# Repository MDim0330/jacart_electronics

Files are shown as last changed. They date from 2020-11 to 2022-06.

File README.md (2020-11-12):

**JACart Electronics Repo**

Contain Python and Arduino controller code for managing the Teleop board.

**Repo Contents**

cart_teleop_dac:/ Updated Arduino teleop code that utilizes DACs instead of PWM signals. This version should be the one used going forward.

python_teleop:/ Stand-alone python controller for teleop_board

libs:/ Require libraries for operating the Arudino teleop code

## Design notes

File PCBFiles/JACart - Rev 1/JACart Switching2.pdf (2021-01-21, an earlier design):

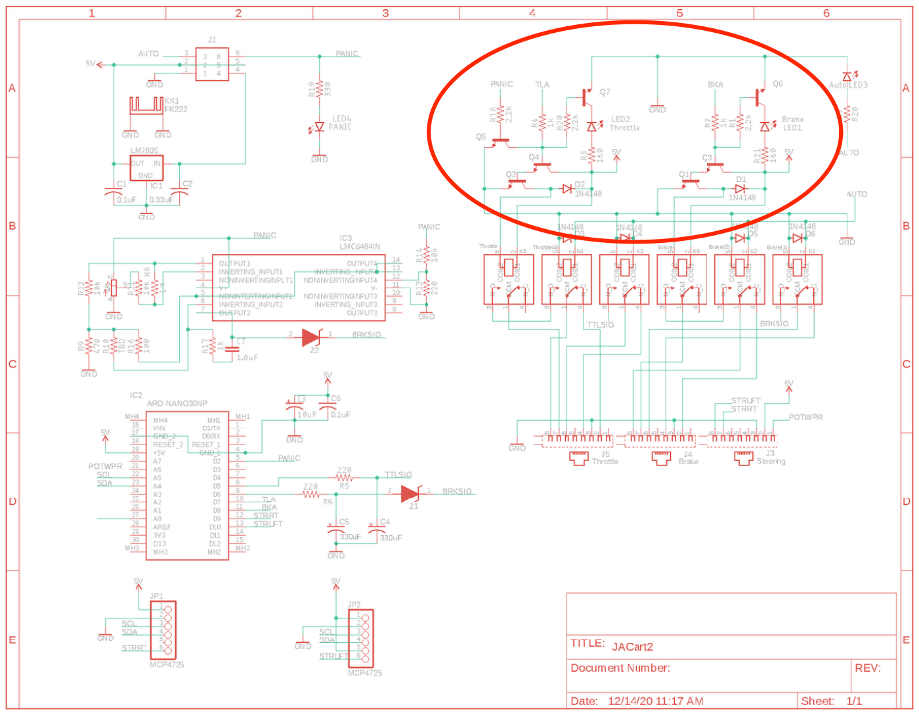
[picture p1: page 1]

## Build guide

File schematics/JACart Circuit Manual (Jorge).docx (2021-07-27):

JACart Circuit Manual:

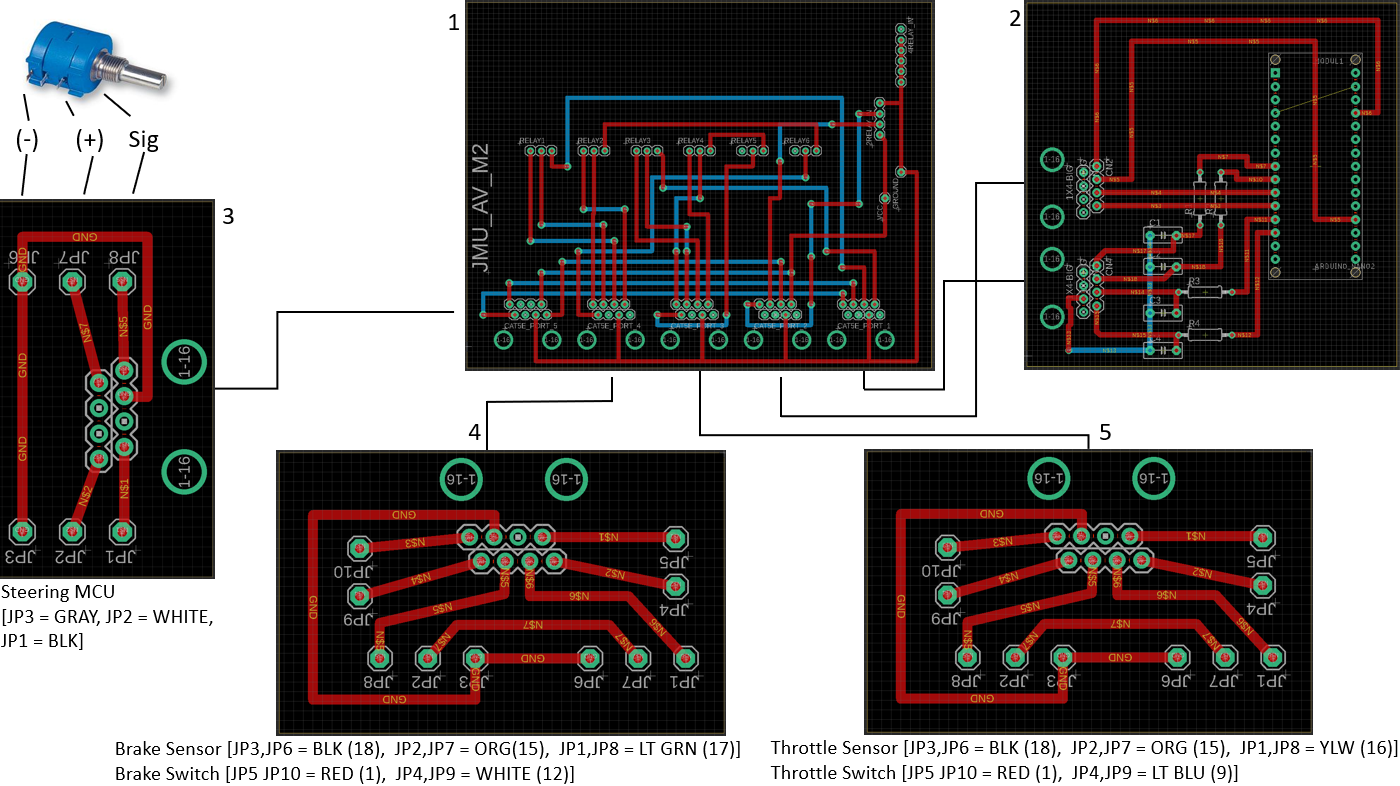
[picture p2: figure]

This manual will review steering, brake, throttle circuits used in the golf cart as of April 2020. Below is an overview of the electronic components involved. A description of each individual board is detailed in subsequent paragraphs.

Figure 1: Complete view of steering, brake, and throttle components in the golf cart.

Overview:

The (INSERT GOLF CART NAME HERE) is selected by the team for this project extension from and earlier model because (WHY DID WE SELECT THIS MODEL?). For the primary controls, i.e., steering, braking and throttle, five individual boards are used: 1 - Motherboard, 2 - Arduino Board, 3 – Steering Board, 4 - Brake Board, 5 - Throttle Board. Each board has its own individual task when in Autonomous Mode.

Each board in Figure 1 was produced by using Eagle Cad. The board view is the only thing visible in this diagram as it is an overview. The solid lines interconnecting each board to the Motherboard represent CAT5e Ethernet cables.

The components needed to exactly replicate this design requires the following:

- Potentiometer (1 required)
  - https://www.digikey.com/product-detail/en/bourns-inc/3590S-2-103L/3590S-2-103L-ND/1088586
- 2-Channel Relay (1 required)
  - https://www.sainsmart.com/products/2-channel-5v-relay-module
- 4-Channel Relay (1 required)
  - https://www.sainsmart.com/products/4-channel-5v-relay-module
- CAT5e Module (10 required)
  - https://www.digikey.com/product-detail/en/assmann-wsw-components/A-2004-2-4-LP-S-R/AE10388-ND/2183639
- Wire to Block Terminal (4 – Two Piece, 6 – Three Piece)
  - https://www.digikey.com/product-detail/en/on-shore-technology-inc/OSTTC022162/ED2609-ND/614558
- Arduino Nano (1 required)
  - https://www.arduino.cc/en/pmwiki.php?n=Main/ArduinoBoardNano
- (###) Resistor (4 required)
  - Link
- (###) Capacitor (4 required)
  - Link

The placement of all these components are discussed in their respective sections in this manual. Text boxes below the steering board, brake board, and throttle board have the specific wires that provide input needed for proper operation. The names of corresponding modules are labeled first, followed by their designated 36-pin MCU connector wire color and pin number connection.

Figure 2 illustrates the main wiring diagram for the golf cart. There are arrows identifying the four specific connection points used for the brake and throttle boards.

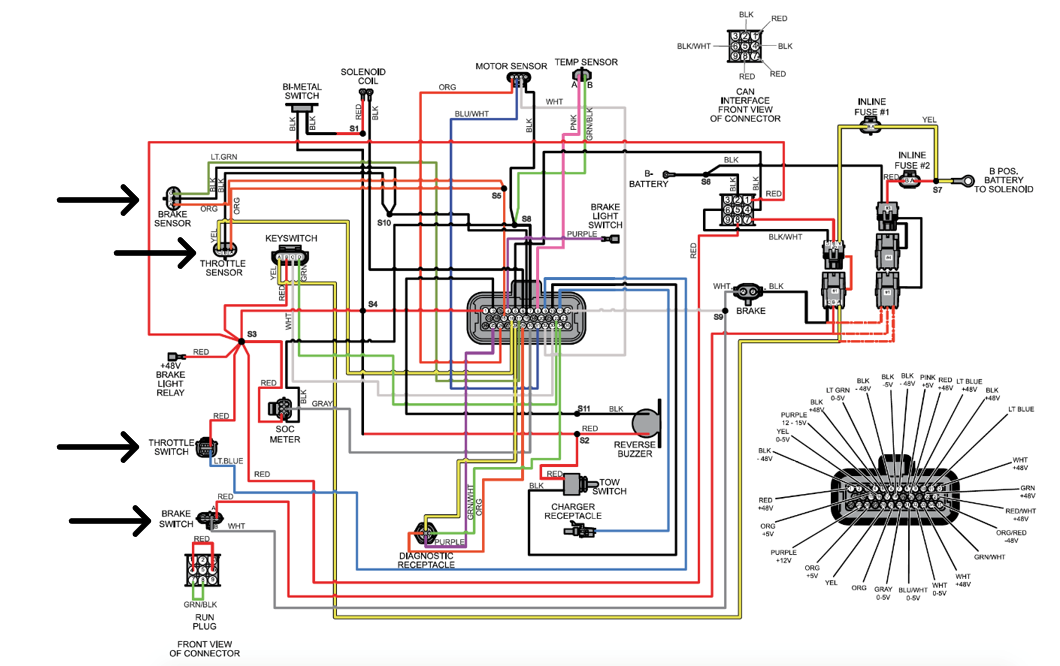
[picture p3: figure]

Figure 2: Main Wiring Harness Diagram of the 36-pin connector from the Golf Cart MCU

1 – Motherboard:

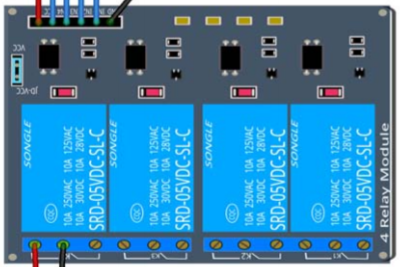
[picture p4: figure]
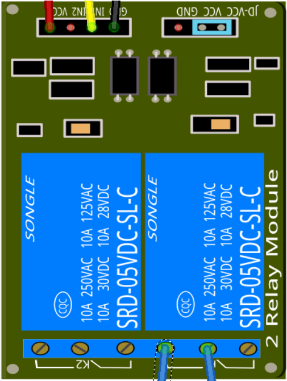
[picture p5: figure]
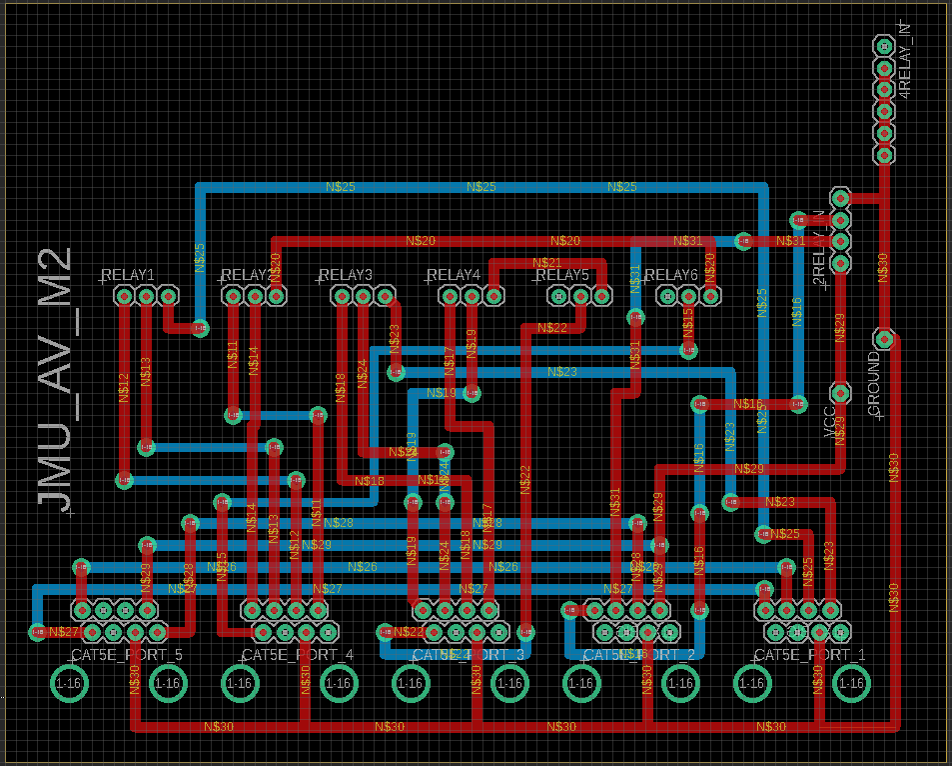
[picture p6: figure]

}

Figure 3: Enlarged Board View (Eagle Cad) of Motherboard and components.

The Motherboard is the main hub for the golf cart’s electronic components. The materials needed to assemble this component completely are: 2-Channel Relay, 4-Channel Relay, 5 Cat5e Modules. The relays will be wired as shown in Figure 3. The 5 Cat5e modules will be placed in the bottom portion of the board. The silkscreen layer of the board has multiple labels named, “CAT5E_PORT#”. These numbers correspond to the boards that we designed as a prototype. Do not pay too much attention to these numbers since the boards each of these ports are assigned to are labeled properly in Figure 1. The upper portion of the board is divided into six segments of 3 wires for each individual relay to make the soldering between board and relays much smoother. The wiring diagram of this board can be seen below in order to better understand.

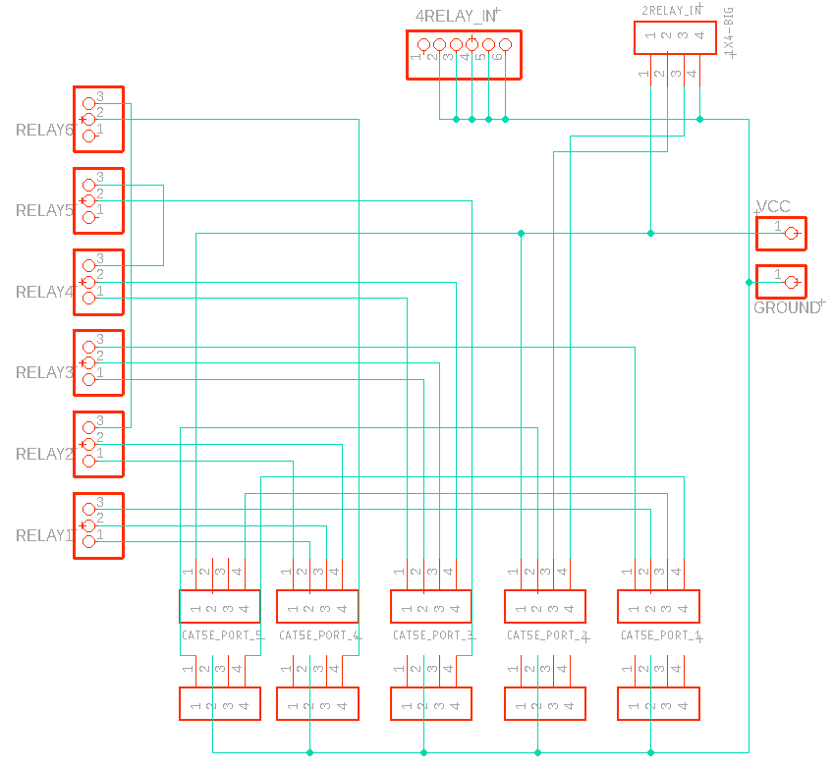
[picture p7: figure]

Figure 4: Enlarged Schematic View of Motherboard component wiring.

2 – Arduino Board:

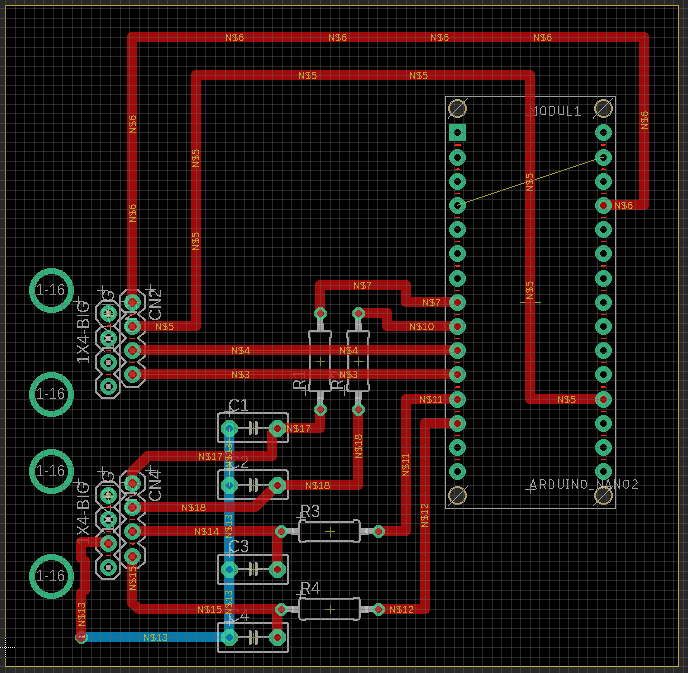
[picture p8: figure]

Figure 5: Enlarged Board View (Eagle Cad) of Arduino Board and components.

(Insert Text Here)

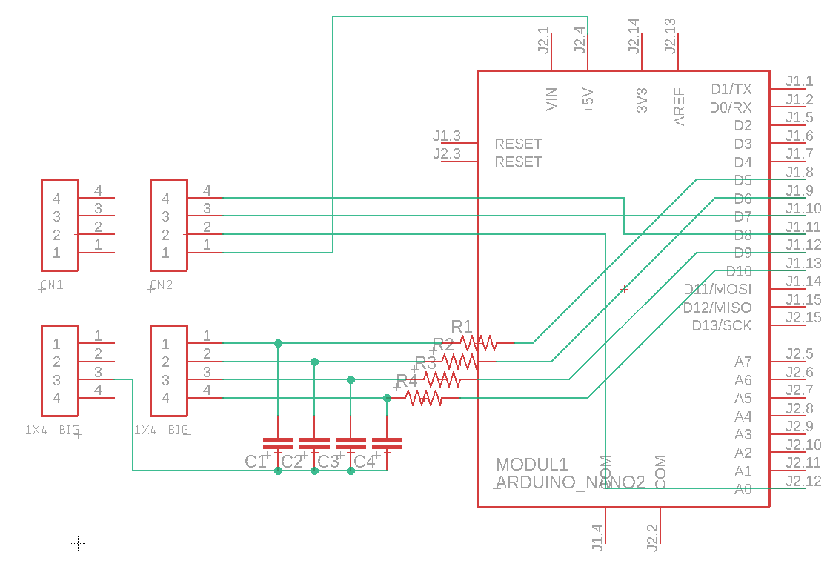
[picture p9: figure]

Figure 6: Enlarged Schematic View of Arduino Board component wiring.

3 – Steering Board:

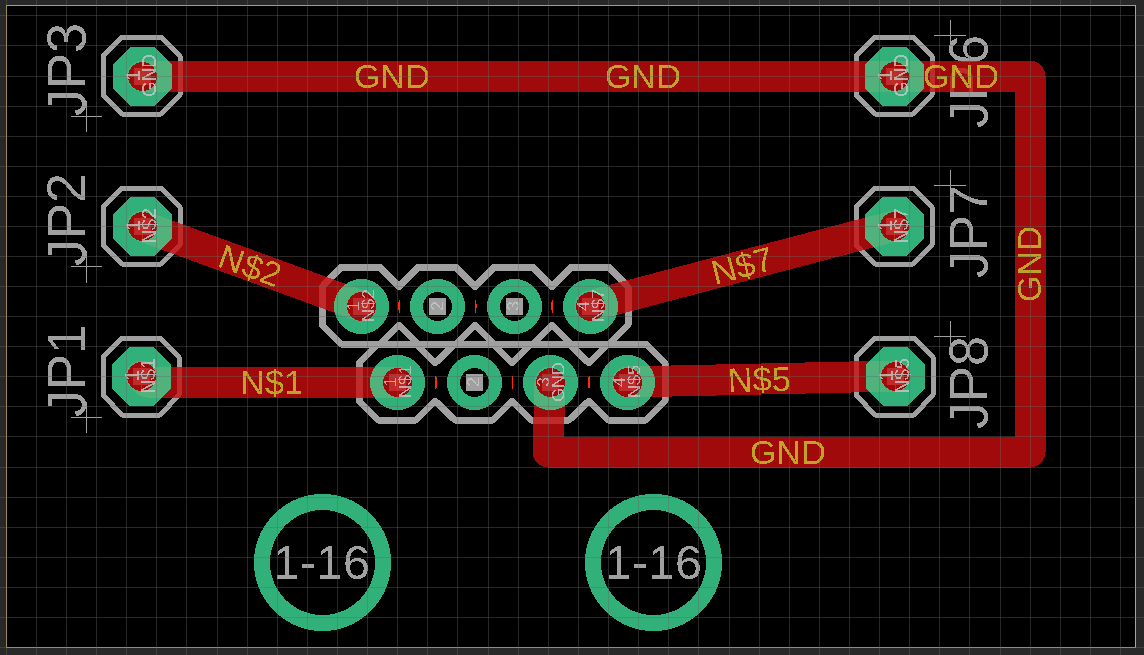
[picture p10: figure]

Figure 7: Enlarged Board View (Eagle Cad) of Steering Board and components.

The Steering board allows us to control all the directional movements within the golf cart. This board only requires a single Cat5e Module that will be placed at the center of the board where the 8 pins are found together. The pins JP6 – JP8 are connected directly to the potentiometer (see Figure 1). This connection allows recovering the current steering wheel rotational position to ensure we are turning at the commanded angle when in Autonomous Mode. This potentiometer is attached to the shaft of the steering column utilizing a custom mount that we had 3D printed. The potentiometer was able to turn and read the angle with a set of gears that were attached to steering column. Pins JP1-JP3 provide access to the Steering MCU so that we may mechanically move the steering to our desired angle when moving autonomously. Figure 8 shows the schematic view of this board.

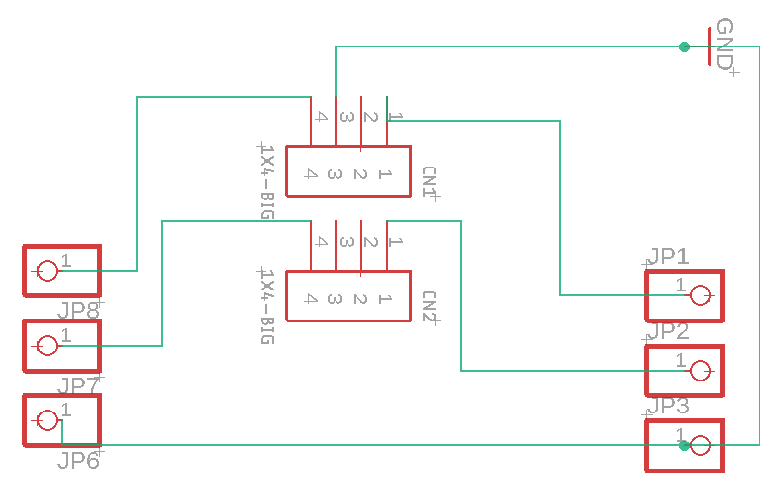
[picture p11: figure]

Figure 8: Enlarged Schematic View of Steering Board component wiring.

4/5 – Brake/Throttle Board:

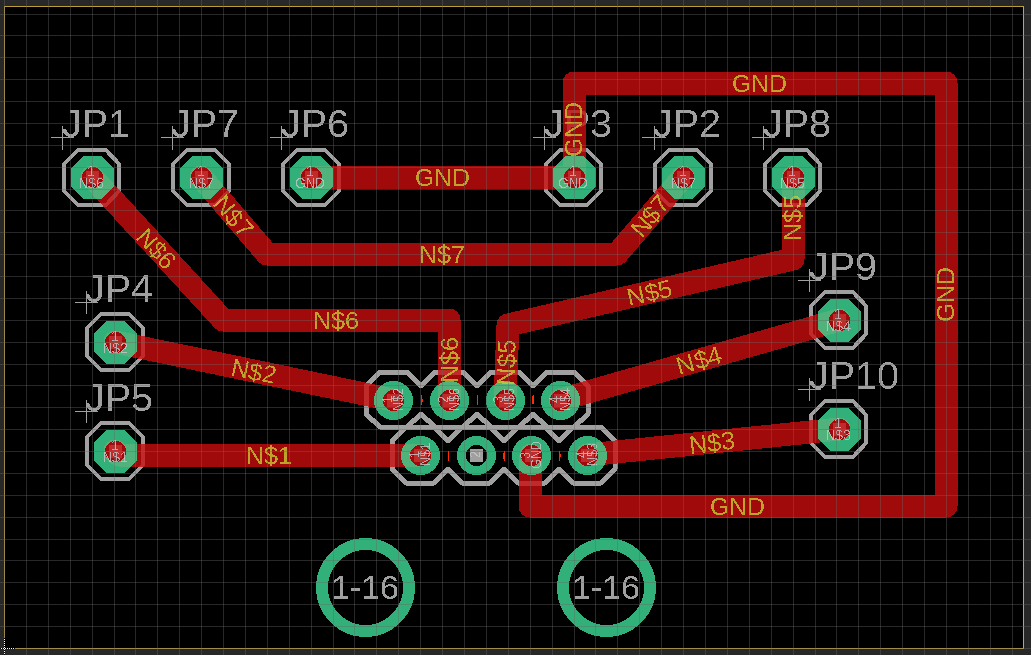
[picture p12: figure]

Figure 9: Enlarged Board View (Eagle Cad) of Brake/Throttle Board and components.

The Brake/Throttle Board requires a single Cat5e Module placed at the center similar to the steering board. These four different sets of pins correspond to individual components found on the golf cart.

The pins on JP1, JP7, JP6, JP3, JP2, JP8 will all be a splice from the Brake Sensor and the Throttle Sensor (each on their respective boards). The pins that are directed toward the MCU here are very important as the voltage inputted into the MCU is the important thing here as this will tell the golf cart how much to accelerate.

The pins on JP4, JP5, JP9, JP10 will all be a splice from the Brake Sensor and the Throttle Sensor (on their respective boards). The switch is used to see when the Brake/Throttle pedals are actually pressed and is sent back to the Motherboard (NEED TO FIGURE THIS OUT MORE AND WRITE MORE ABOUT IT)

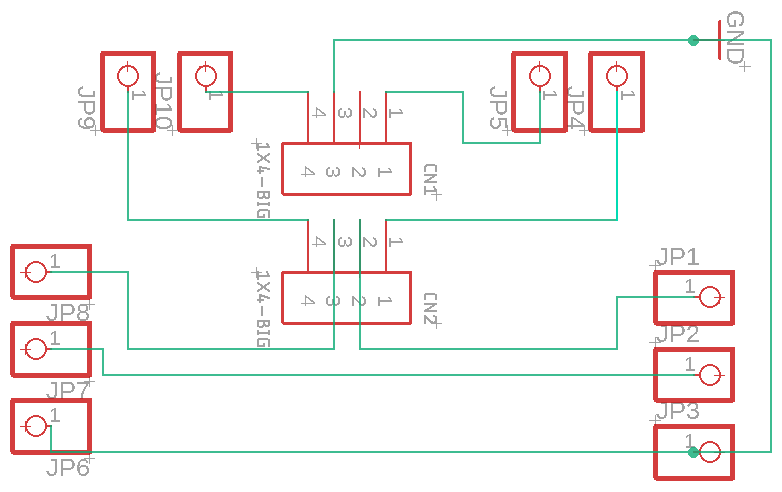
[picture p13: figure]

Figure 10: Enlarged Schematic View of Brake/Throttle Board component wiring.

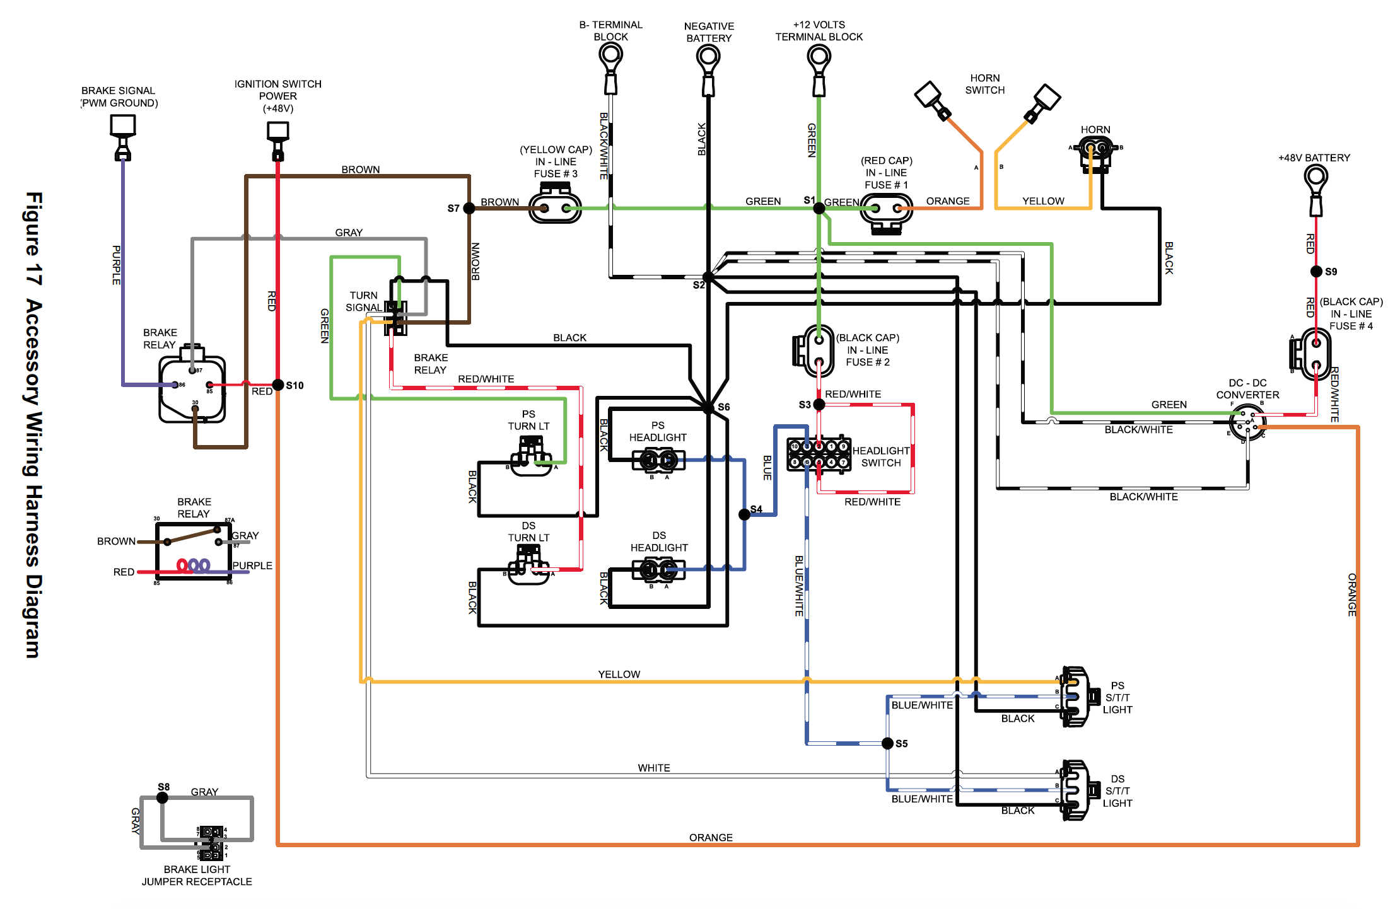
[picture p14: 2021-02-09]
schematics/Golf Cart Wiring #2.png

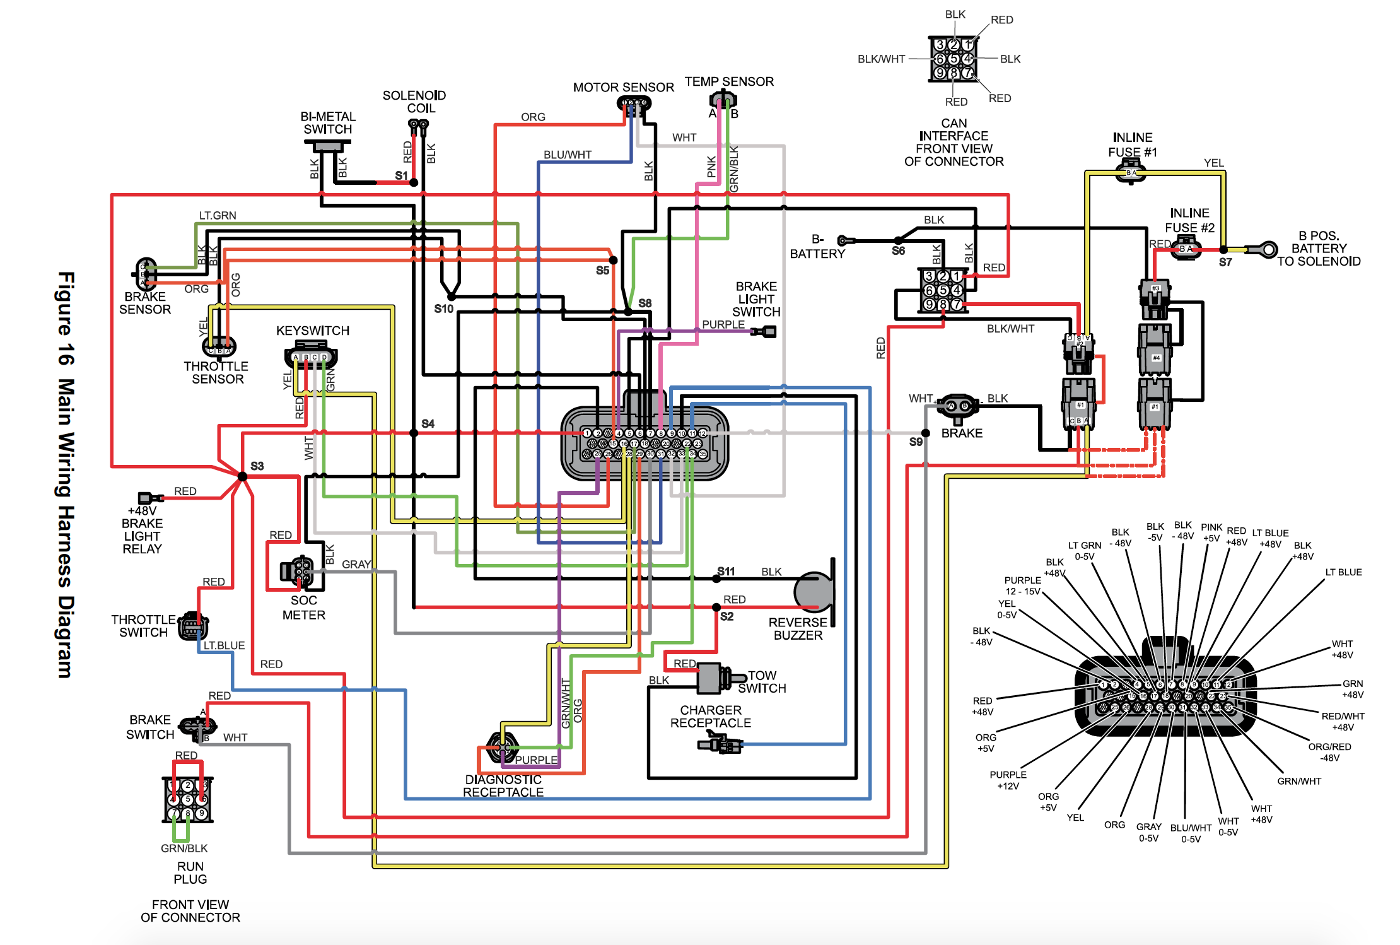
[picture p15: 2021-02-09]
schematics/Golf Cart Wiring #1.png

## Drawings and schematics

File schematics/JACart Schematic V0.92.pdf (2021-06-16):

## Steering Board (#3)

Pot | PSU | MCU

## Brake Board (#4)

Sensor | Switch | MCU

## Throttle Board (#5)

Sensor | Switch | MCU

## Relay Board (#1)

Port 2 | Port 1
Port 3 | Port 4 | Port 5

## Arduino Board (#2)

CN2 | CN4

## USB From Navigation Application

# System Block Diagram Sheet 1

# Board #1: Relay Board Sheet 2 (2021/6/15)

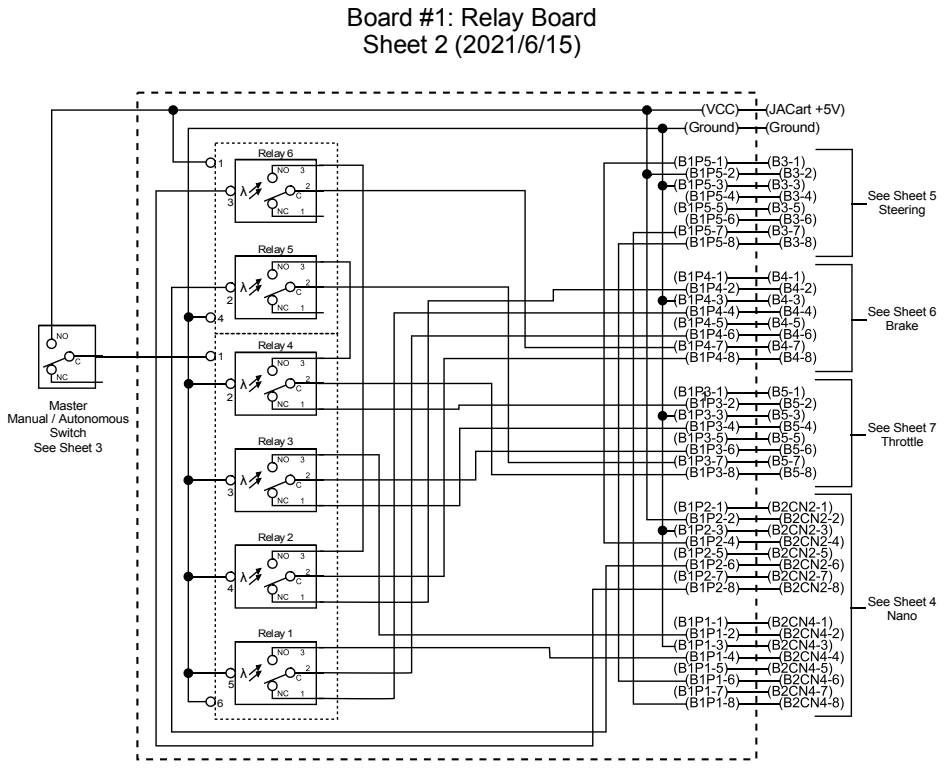
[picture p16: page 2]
Relay 1; Relay 6; Relay 5; Relay 4; Relay 3; Relay 2; (JACart +5V) (Ground); Master Manual / Autonomous Switch See Sheet 3; See Sheet 4 Nano; See Sheet 7 Throttle; See Sheet 6 Brake; See Sheet 5 Steering; (VCC) (Ground)

# Manual / Autonomous Switching Sheet 3

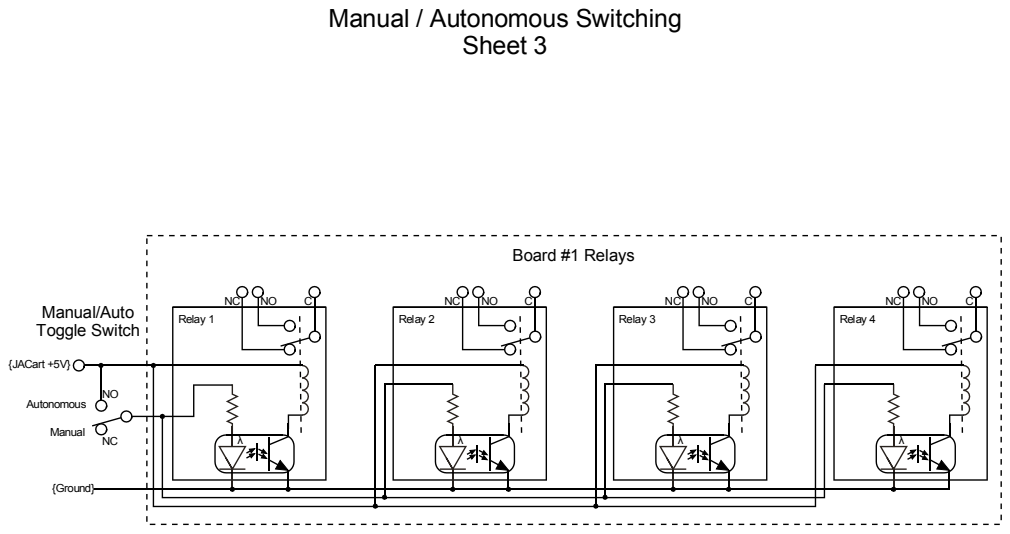
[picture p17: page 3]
Relay 1; Relay 2; Relay 3; Relay 4; {Ground}; {JACart +5V}; Manual; Autonomous; Board #1 Relays; Manual/Auto Toggle Switch

## Navigation Application

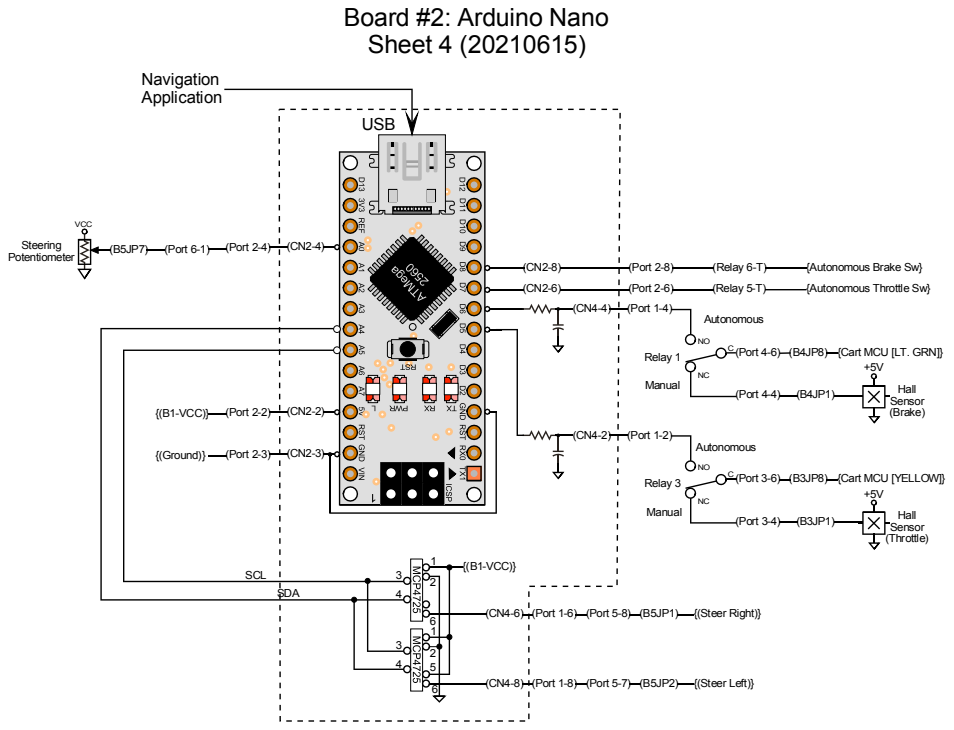
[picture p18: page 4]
Hall Sensor (Throttle); (Port 3-4); (Port 1-2); Relay 3; (Port 3-6) (B3JP8); Manual; Autonomous; {Cart MCU [YELLOW]}; (Port 2-6); (Relay 5-T); {Autonomous Throttle Sw}; Hall Sensor (Brake); (Port 4-4); (Port 1-4); Relay 1; (Port 4-6) (B4JP8); {Cart MCU [LT. GRN]}; (Port 6-1); (Port 2-4); VCC; Steering; Potentiometer; (Port 2-8); (Relay 6-T); {Autonomous Brake Sw}; USB; {(B1-VCC)}; (Port 2-2); {(Ground)}; (Port 2-3); SDA; SCL; (CN4-6) (Port 1-6) (Port 5-8) (B5JP1); {(Steer Right)}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

Board #2: Arduino Nano
Sheet 4 (20210615)

# Board #3: Steering Sheet 5

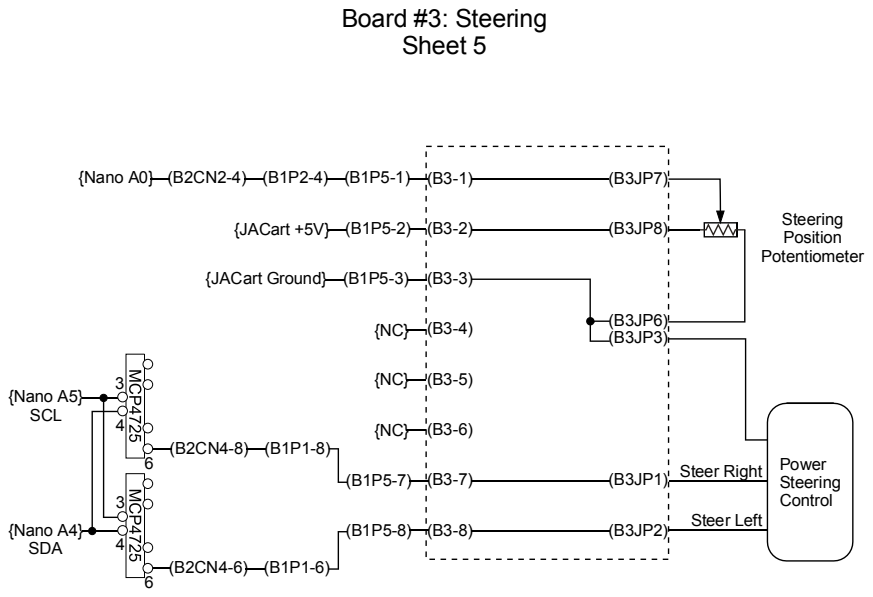
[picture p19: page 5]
Steer Left; Steering Control; Steering Position Potentiometer; {JACart +5V} (B1P5-2); {Nano A0} (B2CN2-4) (B1P2-4) (B1P5-1); {JACart Ground} (B1P5-3); {Nano A5}; {Nano A4}; SCL; SDA

Steer Right Power

# Board #4: Brake Sheet 6

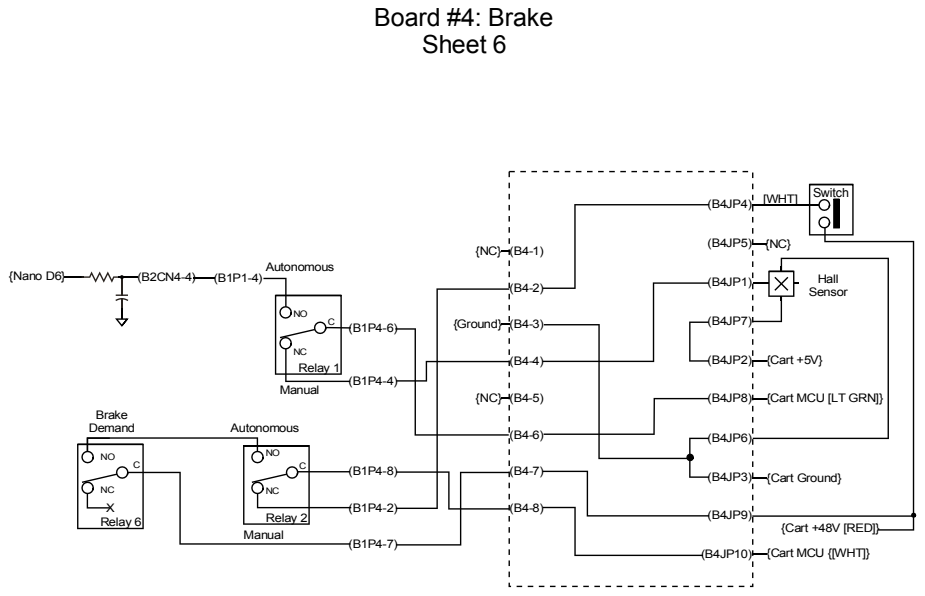
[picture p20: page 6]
{Cart +5V}; {Cart Ground}; Hall Sensor; [WHT]; Switch; Relay 1; Manual; Autonomous; {Nano D6}; {Ground}; Relay 6; Relay 2; Brake Demand

{Cart MCU [LT GRN]}

{Cart +48V [RED]}
{Cart MCU {[WHT]}

# Board #5: Throttle Sheet 7

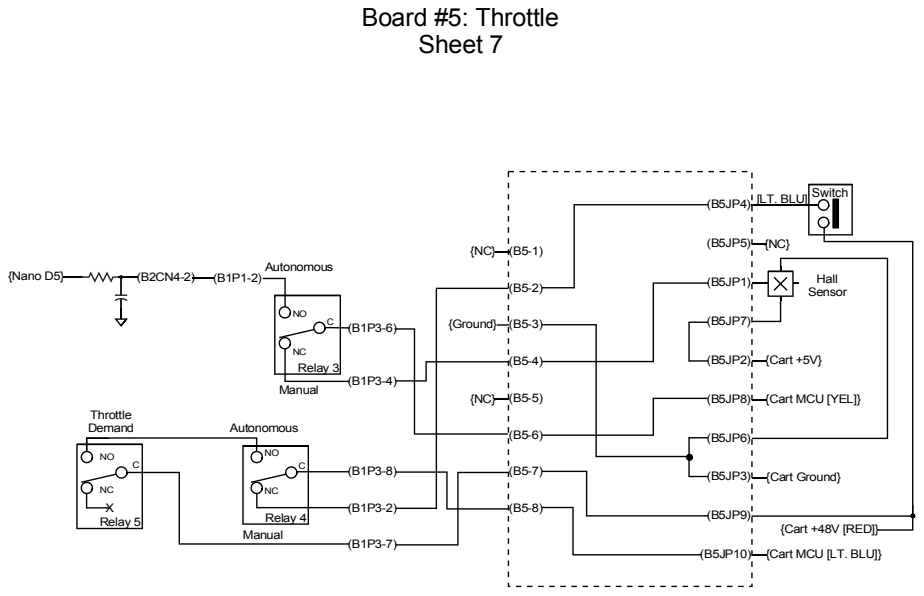
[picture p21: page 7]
{Cart +5V}; {Cart Ground}; Hall Sensor; [LT. BLU]; Switch; Relay 3; Manual; Autonomous; {Nano D5}; {Ground}; Relay 5; Relay 4; Throttle Demand

{Cart MCU [YEL]}

{Cart +48V [RED]}
{Cart MCU [LT. BLU]}

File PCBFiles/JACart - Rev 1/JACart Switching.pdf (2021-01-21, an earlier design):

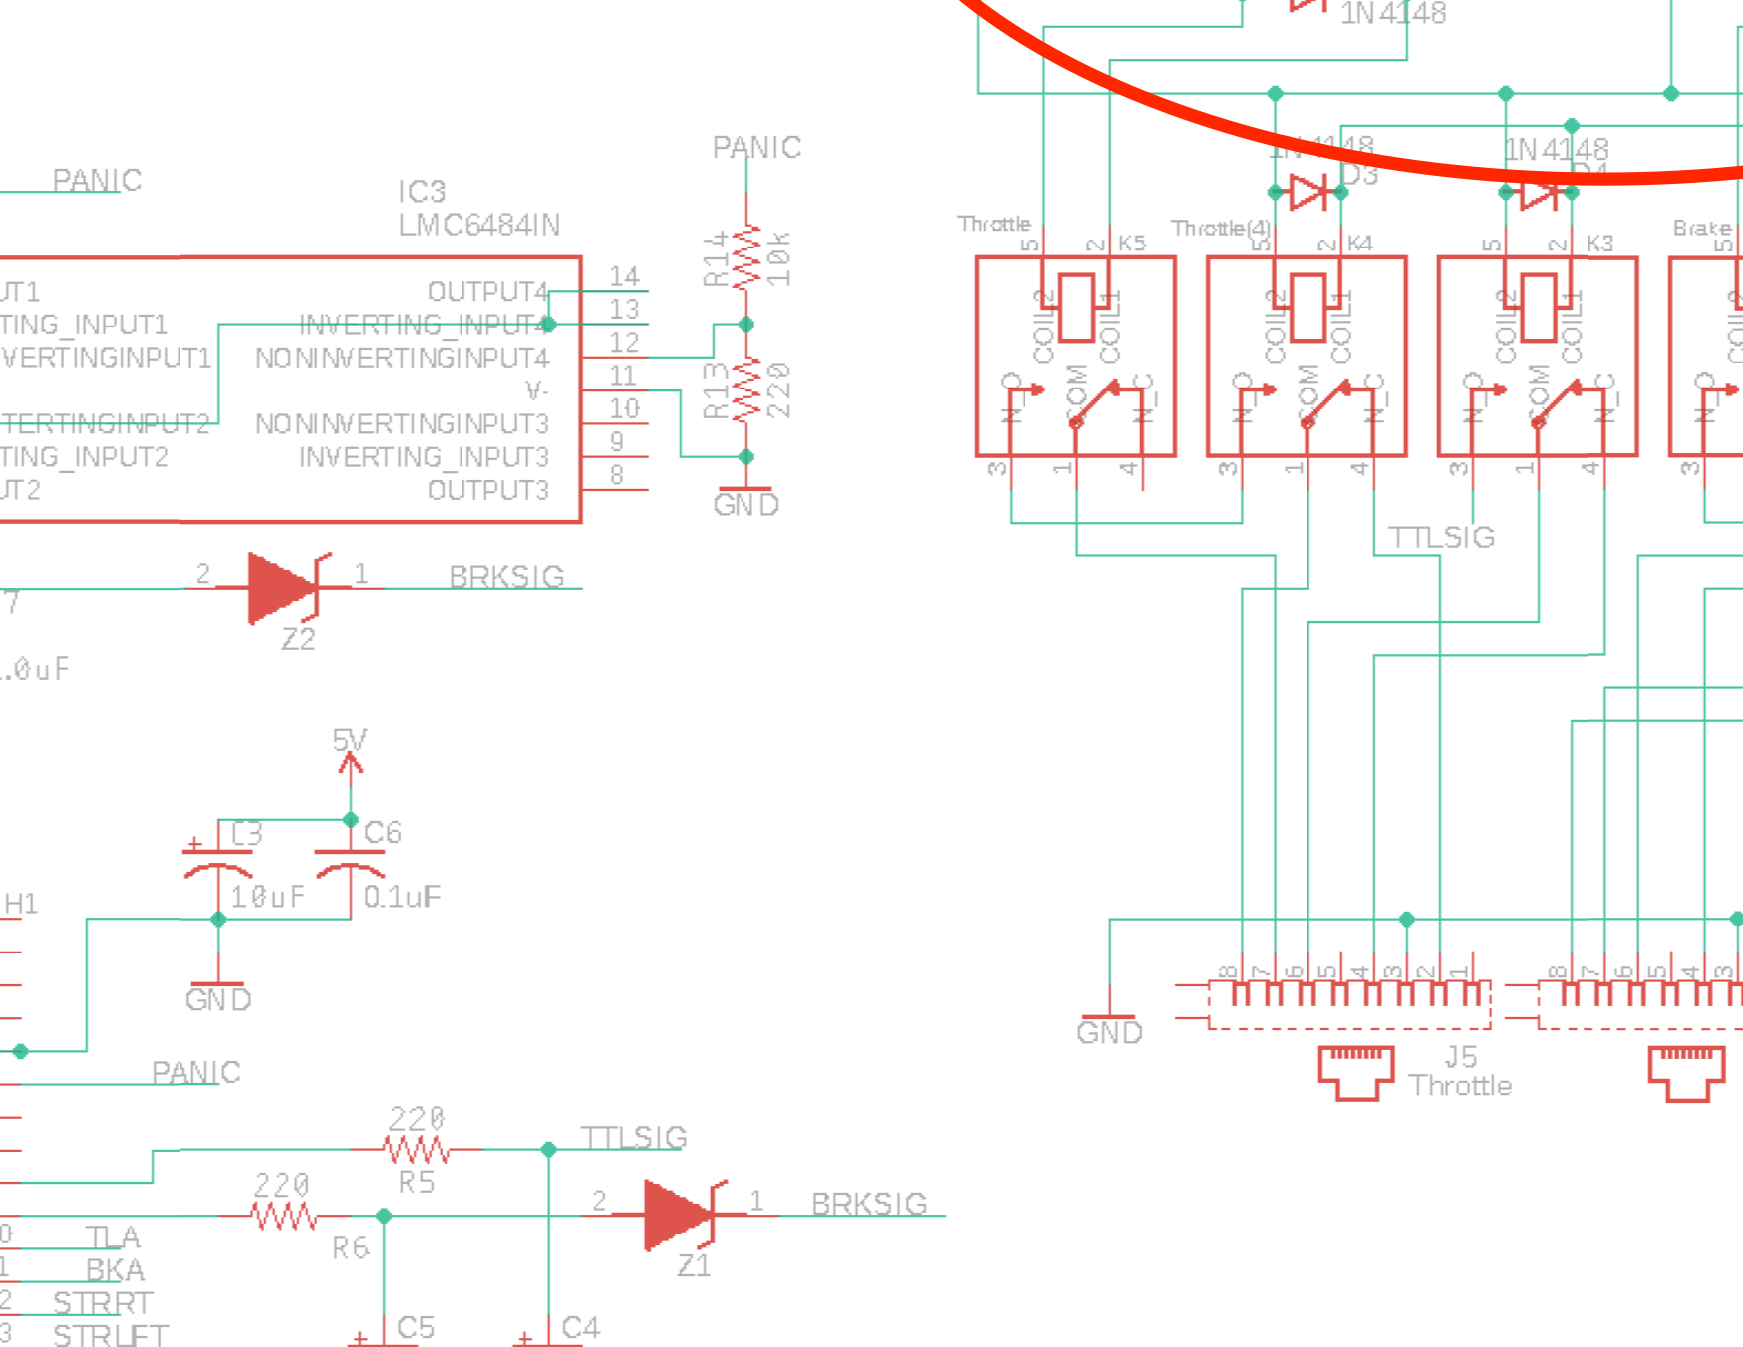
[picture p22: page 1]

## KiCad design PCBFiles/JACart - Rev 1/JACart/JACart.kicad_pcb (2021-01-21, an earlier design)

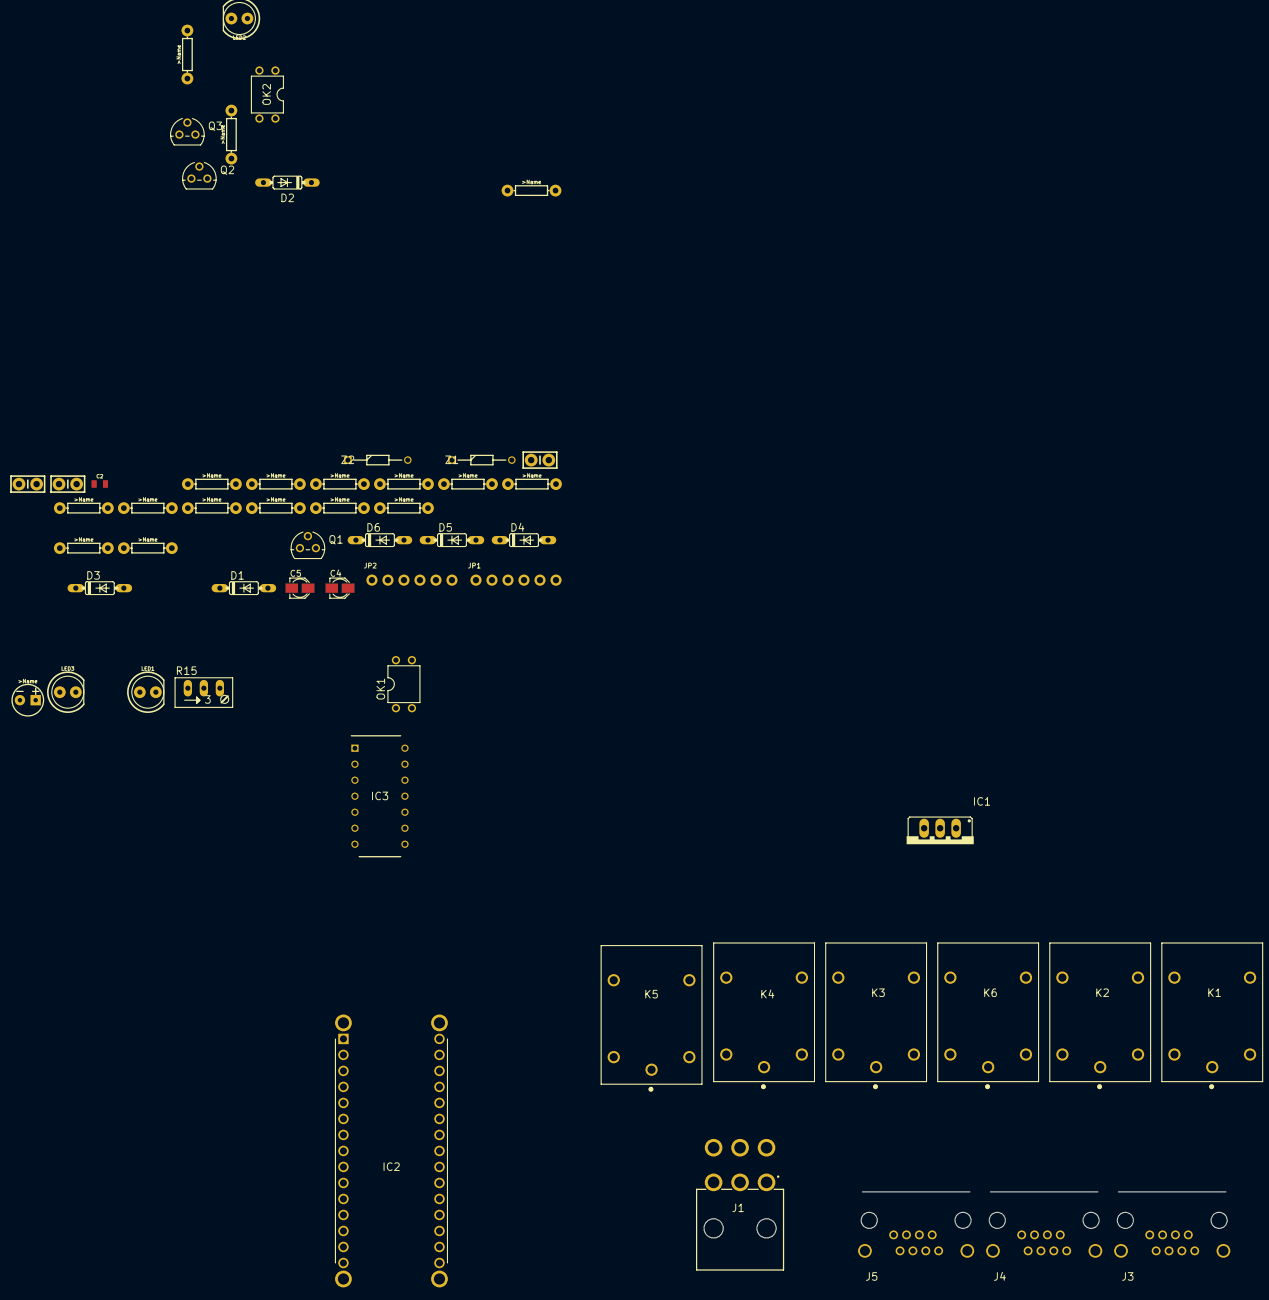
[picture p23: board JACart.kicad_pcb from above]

Board: 2 copper layers, 56 parts (0 on the bottom side), 51 nets, no tracks yet.

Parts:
C1, C6: 0.1uF; CAP-PTH-SMALL-KIT
C2: 0.33µF; 0805
C3: 10uF; CPOL-RADIAL-2.5MM-5MM
C4, C5: 330uF; PANASONIC_A
C7: 1.0uF; CAP-PTH-SMALL-KIT
D1, D2, D3, D4, D5, D6: 1N4148; DO35-7
IC1: LM7805; 78XXS
IC2: ARD-NANO30NP; ARDNANO30NP
IC3: LMC6484IN; DIP794W56P254L1905H533Q14N
J1: 39-30-1060; 39-30-1060_1
J3: Steering; GLX-S-88M
J4: Brake; GLX-S-88M
J5: Throttle; GLX-S-88M
JP1, JP2: MCP4725; 1X06_ROUND_70
K1: Brake(1); RELAY_JS1-5V-F
K2: Brake(2); RELAY_JS1-5V-F
K3: Throttle(3); RELAY_JS1-5V-F
K4: Throttle(4); RELAY_JS1-5V-F
K5: Throttle; RELAY_JS1-5V-F
K6: Brake; RELAY_JS1-5V-F
LED1: Brake; LED_5MM
LED2: Throttle; LED_5MM
LED3: Auto; LED_5MM
OK1, OK2: PC817; DIL04
Q1, Q2, Q3: 2N3904; TO92
R1, R3: 510; AXIAL-0.3
R2, R4, R7, R9: 470; AXIAL-0.3
R5, R6, R13: 220; AXIAL-0.3
R8: 1M; AXIAL-0.3
R10: TBD; AXIAL-0.3
R11, R12, R14: 10k; AXIAL-0.3
R15: 1k; RJ9W
R16: 100; AXIAL-0.3
R17, R18: 1k; AXIAL-0.3
Z1, Z2: BAT85S-TR; DIOAD950W60L350D150

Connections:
5V: C1.1, C3.1, C6.1, D1.C, IC1.OUT, IC2.19, J1.2, J1.5, J3.2, JP1.1, JP2.1, JP2.5, K6.2, OK1.4
/AUTO: D3.C, D4.C, D5.C, D6.C, J1.3, K1.2, K2.2, K3.2, K4.2, R7.P$1
/BKA: IC2.11, R2.P$2
/BRKSIG: K1.3, Z1.1, Z2.1
/PANIC: IC3.4, J1.6, R14.P$2, R15.E, R18.P$2
/POTWPR: IC2.27, J3.1
/SCL: IC2.22, JP1.3, JP2.3
/SDA: IC2.23, JP1.4, JP2.4
/STRLFT: IC2.13, J3.8, JP2.6
/STRRT: IC2.12, J3.7, JP1.6
/TLA: IC2.10, R4.P$2
/TTLSIG: C4.+, K3.3, R5.P$1
GND: C1.2, C2.2, C3.2, C4.-, C5.-, C6.2, D3.A, D4.A, D5.A, D6.A, IC1.GND, IC2.4, IC2.17, IC3.11, J1.1, J3.3, J4.3, J5.3, JP1.2, JP2.2, K1.5, K2.5, K3.5, K4.5, LED1.K, LED2.K, LED3.K, Q1.3, Q2.3, Q3.3, R9.P$1, R13.P$1, R15.A
unnamed: C2.1, IC1.IN, J1.4
unnamed: C5.+, R6.P$1, Z1.2
unnamed: C7.1, IC3.7, Z2.2
unnamed: C7.2, R17.P$1
unnamed: D1.A, K6.5, Q1.1
unnamed: D2.A, K5.5, Q2.1
unnamed: D2.C, K5.2, OK2.4
unnamed: IC2.8, R5.P$2
unnamed: IC2.9, R6.P$2
unnamed: IC3.1, R8.P$2, R12.P$2
unnamed: IC3.2, R8.P$1, R11.P$1
unnamed: IC3.6, R10.P$1, R17.P$2
unnamed: IC3.12, R13.P$2, R14.P$1
unnamed: IC3.5, IC3.13, IC3.14, R16.P$1
unnamed: J4.2, K2.4
unnamed: J4.4, K1.4
unnamed: J4.6, K1.1
unnamed: J4.7, K6.1
unnamed: J4.8, K2.1
unnamed: J5.2, K4.4
unnamed: J5.4, K3.4
unnamed: J5.6, K3.1
unnamed: J5.7, K5.1
unnamed: J5.8, K4.1
unnamed: K2.3, K6.3
unnamed: K4.3, K5.3
unnamed: LED1.A, OK1.2
unnamed: LED2.A, OK2.2
unnamed: LED3.A, R7.P$2
unnamed: OK1.1, R2.P$1
unnamed: OK1.3, R1.P$2
unnamed: OK2.1, R4.P$1
unnamed: OK2.3, R3.P$2
unnamed: Q1.2, R1.P$1
unnamed: Q2.2, Q3.1, R3.P$1
unnamed: Q3.2, R18.P$1
unnamed: R9.P$2, R10.P$2, R12.P$1, R16.P$2
unnamed: R11.P$2, R15.S

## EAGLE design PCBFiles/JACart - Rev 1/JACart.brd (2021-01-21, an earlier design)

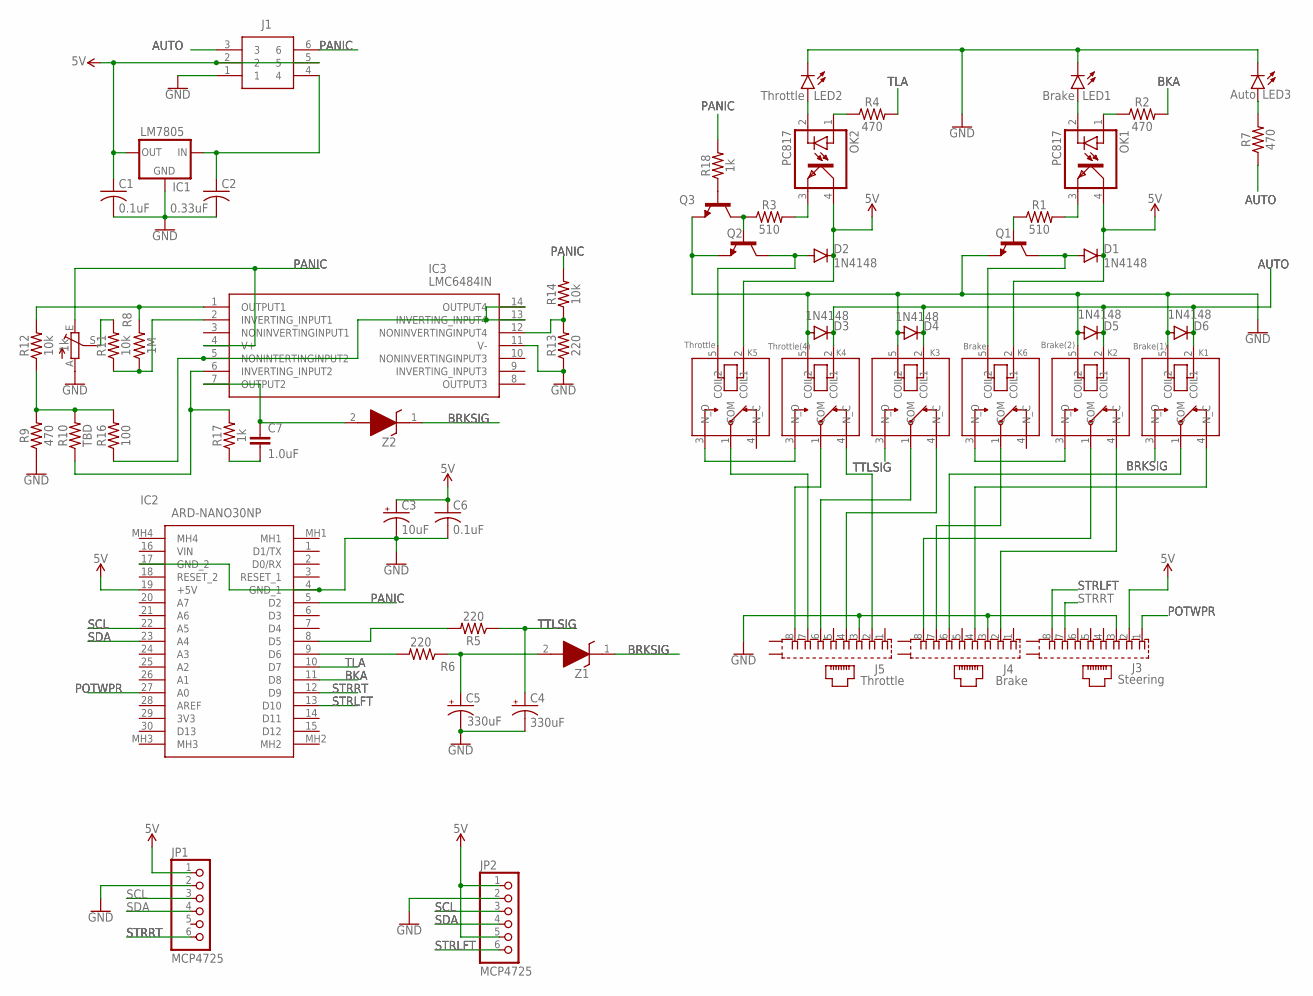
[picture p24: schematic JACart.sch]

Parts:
C1, C6: 0.1uF; C050-024X044
C2: 0.33uF; C050-024X044
C3: 10uF; CPOL-RADIAL-2.5MM-5MM
C4, C5: 330uF; PANASONIC_A
C7: 1.0uF; CAP-PTH-SMALL-KIT
D1, D2, D3, D4, D5, D6: 1N4148; DO35-7
IC1: LM7805; 78XXS
IC2: ARD-NANO30NP; ARDNANO30NP
IC3: LMC6484IN; DIP794W56P254L1905H533Q14N
J1: 39-30-1060; 39-30-1060_1
J3: Steering; GLX-S-88M
J4: Brake; GLX-S-88M
J5: Throttle; GLX-S-88M
JP1, JP2: MCP4725; 1X06_ROUND_70
K1: Brake(1); RELAY_JS1-5V-F
K2: Brake(2); RELAY_JS1-5V-F
K3: Throttle(3); RELAY_JS1-5V-F
K4: Throttle(4); RELAY_JS1-5V-F
K5: Throttle; RELAY_JS1-5V-F
K6: Brake; RELAY_JS1-5V-F
LED1: Brake; LED_5MM
LED2: Throttle; LED_5MM
LED3: Auto; LED_5MM
OK1, OK2: PC817; DIL04
Q1, Q2, Q3: 2N3904; TO92
R1, R3: 510; AXIAL-0.3
R2, R4, R7, R9: 470; AXIAL-0.3
R5, R6, R13: 220; AXIAL-0.3
R8: 1M; AXIAL-0.3
R10: TBD; AXIAL-0.3
R11, R12, R14: 10k; AXIAL-0.3
R15: 1k; RJ9W
R16: 100; AXIAL-0.3
R17, R18: 1k; AXIAL-0.3
Z1, Z2: BAT85S-TR; DIOAD950W60L350D150

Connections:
5V: C1.1, C3.1 (+), C6.1, D1.C, D2.C, IC1.OUT, IC2.19 (+5V), J1.2, J1.5, J3.2, JP1.1, JP2.1, JP2.5, K5.2 (COIL1), K6.2 (COIL1), OK1.4 (COL), OK2.4 (COL)
AUTO: D3.C, D4.C, D5.C, D6.C, J1.3, K1.2 (COIL1), K2.2 (COIL1), K3.2 (COIL1), K4.2 (COIL1), R7.P$1 (1)
BKA: IC2.11 (D8), R2.P$2 (2)
BRKSIG: K1.3 (N_O), Z1.1 (K), Z2.1 (K)
GND: C1.2, C2.2, C3.2 (-), C4.-, C5.-, C6.2, D3.A, D4.A, D5.A, D6.A, IC1.GND, IC2.4 (GND_1), IC2.17 (GND_2), IC3.11 (V-), J1.1, J3.3, J4.3, J5.3, JP1.2, JP2.2, K1.5 (COIL2), K2.5 (COIL2), K3.5 (COIL2), K4.5 (COIL2), LED1.K (C), LED2.K (C), LED3.K (C), Q1.3 (E), Q2.3 (E), Q3.3 (E), R9.P$1 (1), R13.P$1 (1), R15.A
unnamed: C2.1, IC1.IN, J1.4
unnamed: D1.A, K6.5 (COIL2), Q1.1 (C)
unnamed: OK2.1 (A), R4.P$1 (1)
unnamed: LED3.A, R7.P$2 (2)
unnamed: OK2.3 (EMIT), R3.P$2 (2)
unnamed: Q2.2 (B), Q3.1 (C), R3.P$1 (1)
unnamed: OK1.1 (A), R2.P$1 (1)
unnamed: LED2.A, OK2.2 (C)
unnamed: LED1.A, OK1.2 (C)
unnamed: IC2.9 (D6), R6.P$2 (2)
unnamed: IC2.8 (D5), R5.P$2 (2)
unnamed: OK1.3 (EMIT), R1.P$2 (2)
unnamed: Q1.2 (B), R1.P$1 (1)
unnamed: D2.A, K5.5 (COIL2), Q2.1 (C)
unnamed: J5.4, K3.4 (N_C)
unnamed: R9.P$2 (2), R10.P$2 (2), R12.P$1 (1), R16.P$2 (2)
unnamed: K2.3 (N_O), K6.3 (N_O)
unnamed: K4.3 (N_O), K5.3 (N_O)
unnamed: J5.7, K5.1 (COM)
unnamed: J5.8, K4.1 (COM)
unnamed: J5.2, K4.4 (N_C)
unnamed: J5.6, K3.1 (COM)
unnamed: J4.7, K6.1 (COM)
unnamed: J4.8, K2.1 (COM)
unnamed: J4.2, K2.4 (N_C)
unnamed: J4.6, K1.1 (COM)
unnamed: J4.4, K1.4 (N_C)
unnamed: IC3.1 (OUTPUT1), R8.P$2 (2), R12.P$2 (2)
unnamed: IC3.2 (INVERTING_INPUT1), R8.P$1 (1), R11.P$1 (1)
unnamed: IC3.5 (NONINTERTINGINPUT2), IC3.13 (INVERTING_INPUT4), IC3.14 (OUTPUT4), R16.P$1 (1)
unnamed: IC3.12 (NONINVERTINGINPUT4), R13.P$2 (2), R14.P$1 (1)
unnamed: R11.P$2 (2), R15.S
unnamed: IC3.6 (INVERTING_INPUT2), R10.P$1 (1), R17.P$2 (2)
unnamed: C7.1, IC3.7 (OUTPUT2), Z2.2 (A)
unnamed: C7.2, R17.P$1 (1)
unnamed: C5.+, R6.P$1 (1), Z1.2 (A)
unnamed: Q3.2 (B), R18.P$1 (1)
PANIC: IC2.5 (D2), IC3.4 (V+), J1.6, R14.P$2 (2), R15.E, R18.P$2 (2)
POTWPR: IC2.27 (A0), J3.1
SCL: IC2.22 (A5), JP1.3, JP2.3
SDA: IC2.23 (A4), JP1.4, JP2.4
STRLFT: IC2.13 (D10), J3.8, JP2.6
STRRT: IC2.12 (D9), J3.7, JP1.6
TLA: IC2.10 (D7), R4.P$2 (2)
TTLSIG: C4.+, K3.3 (N_O), R5.P$1 (1)

Board: 2 copper layers, 56 parts (0 on the bottom side), 50 nets, no tracks yet.

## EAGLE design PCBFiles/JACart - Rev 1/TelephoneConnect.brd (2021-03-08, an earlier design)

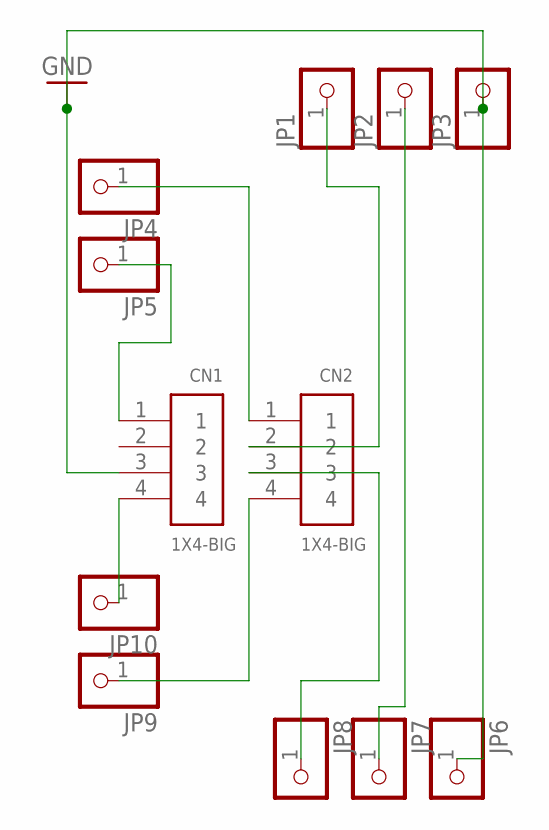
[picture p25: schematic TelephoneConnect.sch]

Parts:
CN1, CN2: 1X4-BIG; 1X04-BIG
JP1, JP2, JP3, JP4, JP5, JP6, JP7, JP8, JP9, JP10: PINHD-1X1; 1X01

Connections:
GND: CN1.3, JP3.1, JP6.1
unnamed: CN1.1, JP5.1
unnamed: CN2.1, JP4.1
unnamed: CN1.4, JP10.1
unnamed: CN2.4, JP9.1
unnamed: CN2.3, JP8.1
unnamed: CN2.2, JP1.1
unnamed: JP2.1, JP7.1

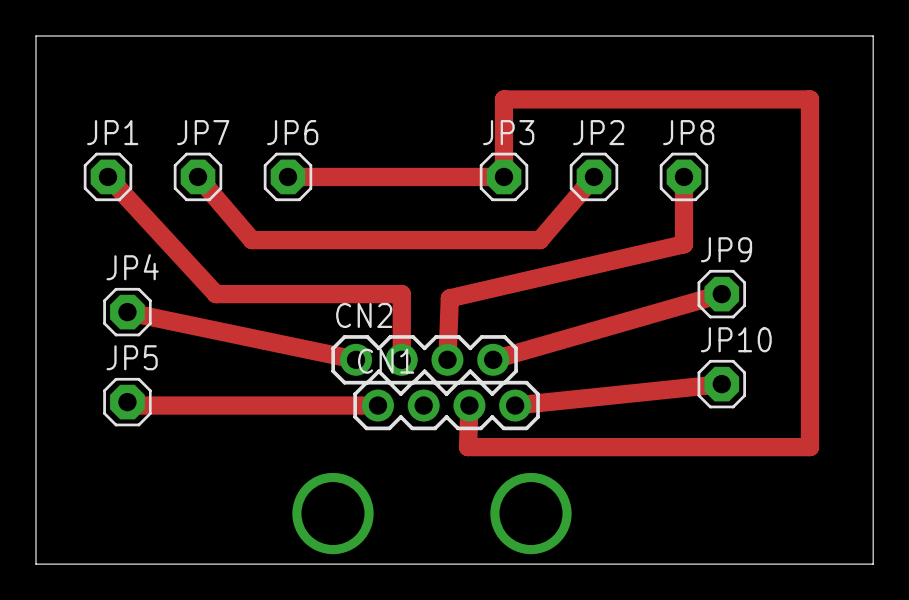
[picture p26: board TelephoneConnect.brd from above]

Board: 2 copper layers, 46.5 x 29.3 mm, 12 parts (0 on the bottom side), 8 nets.

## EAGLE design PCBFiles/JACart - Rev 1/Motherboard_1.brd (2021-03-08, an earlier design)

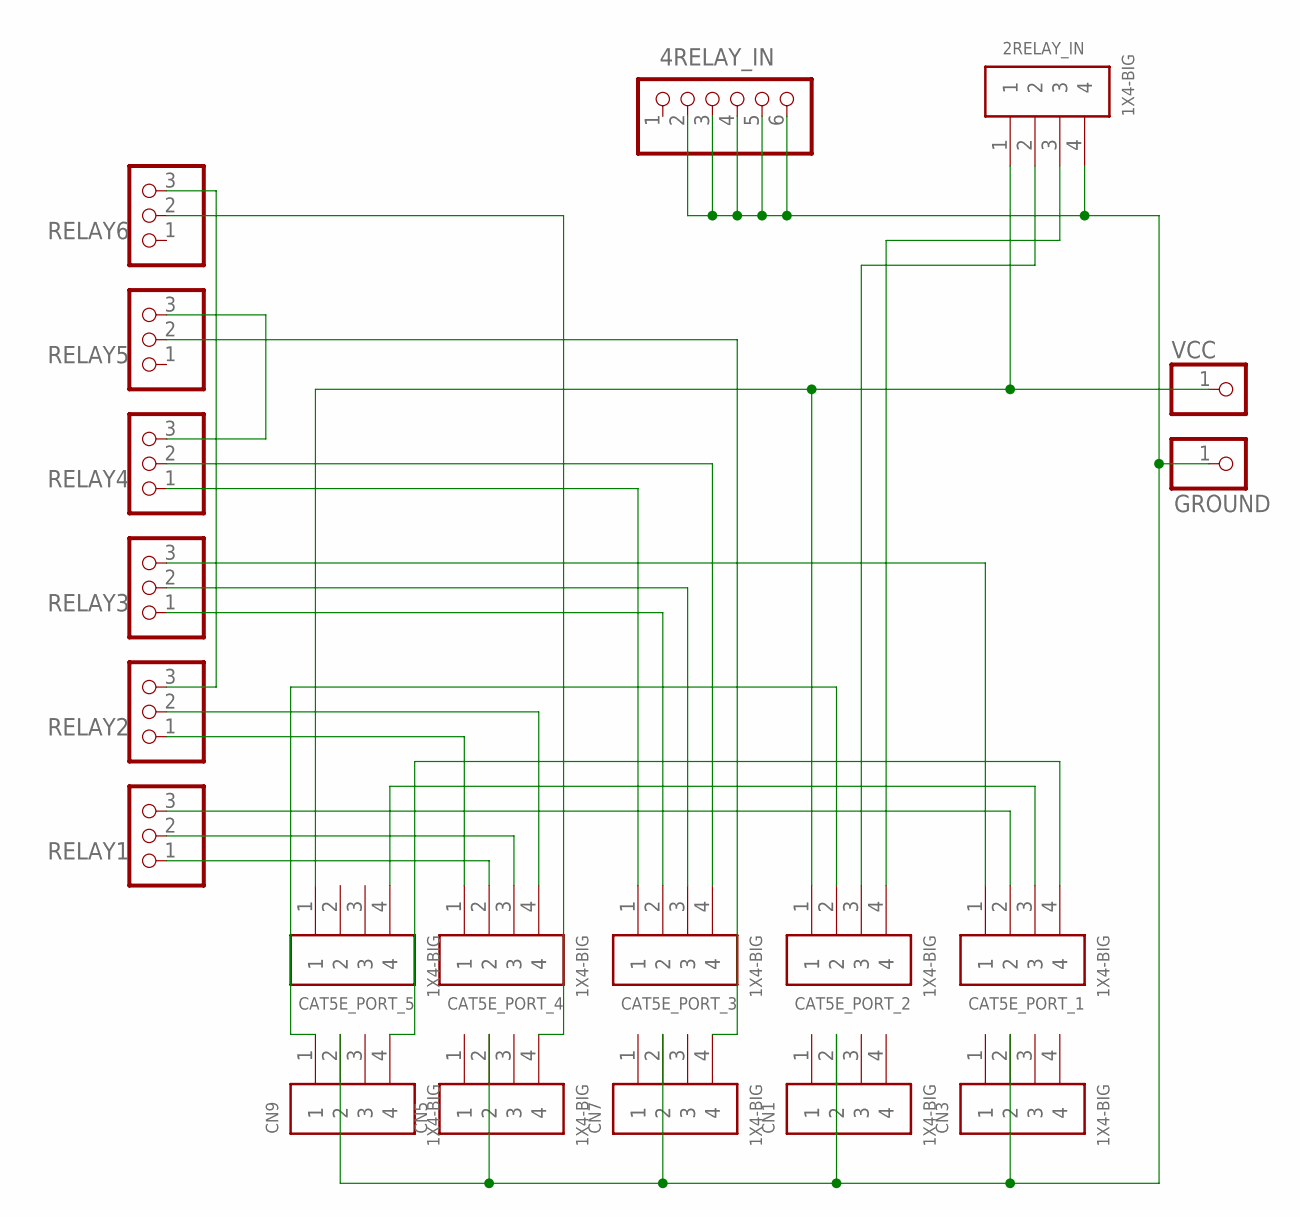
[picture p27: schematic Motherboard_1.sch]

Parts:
2RELAY_IN: 1X4-BIG; 1X04-BIG
4RELAY_IN: PINHD-1X6; 1X06
CAT5E_PORT_1, CAT5E_PORT_2, CAT5E_PORT_3, CAT5E_PORT_4, CAT5E_PORT_5: 1X4-BIG; 1X04-BIG
CN1, CN3, CN5, CN7, CN9: 1X4-BIG; 1X04-BIG
GROUND: PINHD-1X1; 1X01
RELAY1, RELAY2, RELAY3, RELAY4, RELAY5, RELAY6: PINHD-1X3; 1X03
VCC: PINHD-1X1; 1X01

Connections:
unnamed: CAT5E_PORT_4.1, RELAY2.1
unnamed: CAT5E_PORT_4.2, RELAY1.1
unnamed: CAT5E_PORT_4.3, RELAY1.2
unnamed: CAT5E_PORT_4.4, RELAY2.2
unnamed: CN5.4, RELAY6.2
unnamed: 2RELAY_IN.3, CAT5E_PORT_2.4
unnamed: CAT5E_PORT_3.1, RELAY4.1
unnamed: CAT5E_PORT_3.2, RELAY3.1
unnamed: CAT5E_PORT_3.4, RELAY4.2
unnamed: RELAY2.3, RELAY6.3
unnamed: RELAY4.3, RELAY5.3
unnamed: CN7.4, RELAY5.2
unnamed: CAT5E_PORT_1.1, RELAY3.3
unnamed: CAT5E_PORT_3.3, RELAY3.2
unnamed: CAT5E_PORT_1.2, RELAY1.3
unnamed: CAT5E_PORT_1.3, CAT5E_PORT_5.4
unnamed: CAT5E_PORT_1.4, CN9.4
unnamed: CAT5E_PORT_2.2, CN9.1
unnamed: 2RELAY_IN.1, CAT5E_PORT_2.1, CAT5E_PORT_5.1, VCC.1
unnamed: 2RELAY_IN.4, 4RELAY_IN.2, 4RELAY_IN.3, 4RELAY_IN.4, 4RELAY_IN.5, 4RELAY_IN.6, CN1.2, CN3.2, CN5.2, CN7.2, CN9.2, GROUND.1
unnamed: 2RELAY_IN.2, CAT5E_PORT_2.3

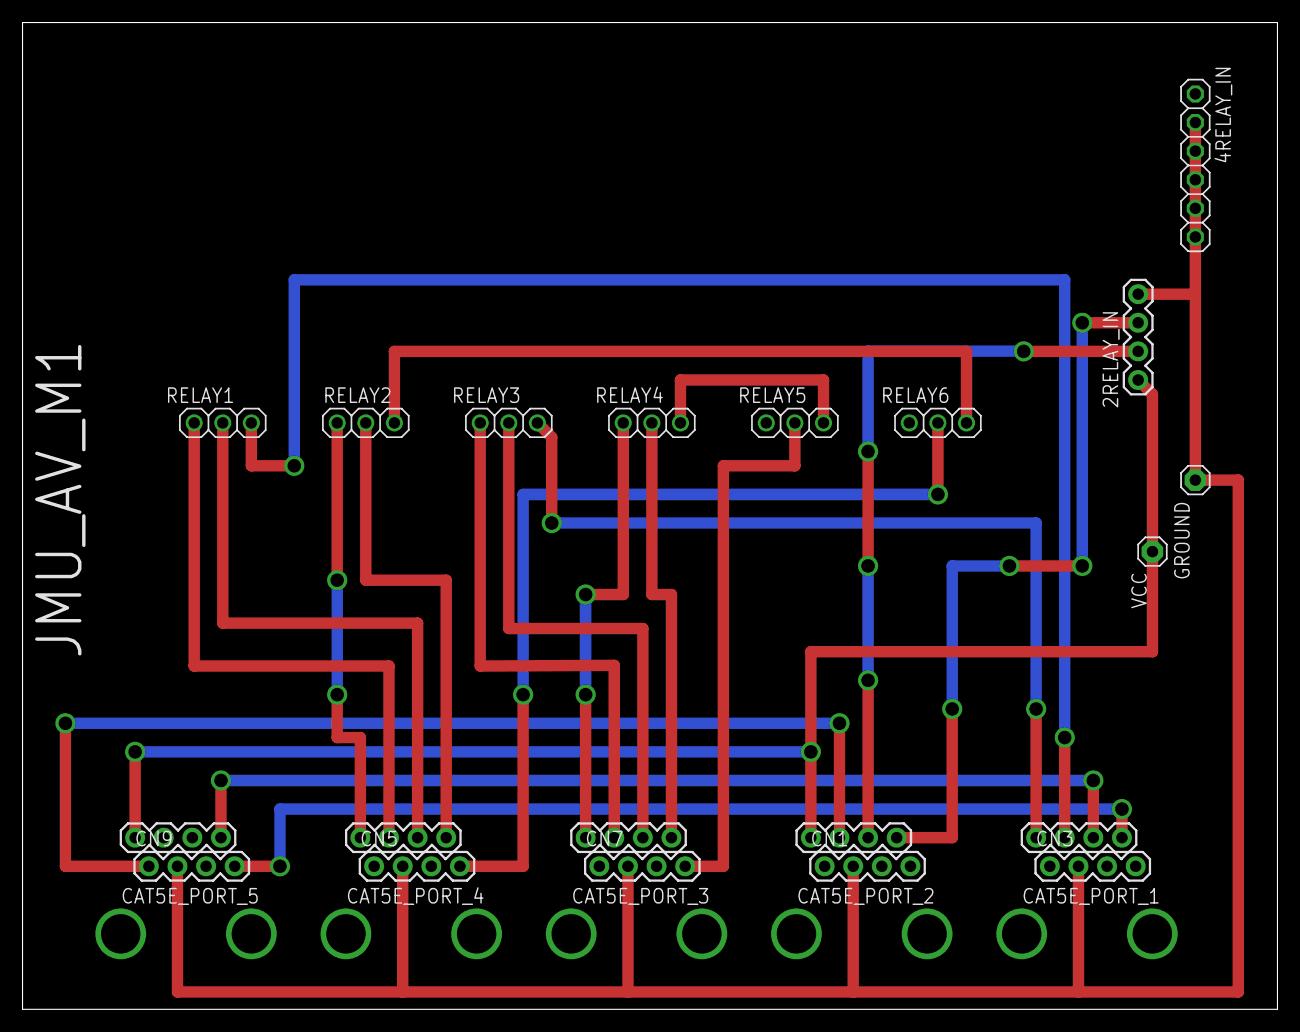
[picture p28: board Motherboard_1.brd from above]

Board: 2 copper layers, 111.4 x 87.6 mm, 20 parts (0 on the bottom side), 21 nets.

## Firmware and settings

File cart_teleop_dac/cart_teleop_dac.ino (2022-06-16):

/*
   cart_teleop_new_board.ino - Contains the main arduino code for controlling our autonomous golf cart with MCP4725 DACs.

      Author: Brandon Parr
      Version: 0.5

       11/09/2020: modified by Dick Shimp to include the MCP4725 DAC development boards
       12/9/2020: edited by Jason Forsyth to increase code structure and readability
       1/21/2021: edited by Jason Forsyth to comment out all Serial.print() statements

       4/29/2021: modified LOWER_BRAKE_BOUND to deal with intermittent stopping condition. Also, reduced
       print statement verbosity to report steering, throttle, and braking targets.

       5/12/2022: modified by Matty Wolfson to tune steering PIDs

       &&&&& NOTE: You must use the Arduino Nano "OLD BOOTLOADER" setting when programming this device!!! Tools -> Processor -> ATMega 328P (Old Bootloader)
*/

#include <Wire.h>
#include <PID_v1.h>
#include <Adafruit_MCP4725.h>

int throttle = 5;      /* pin 3 */
int brake = 6;         /* pin 5 */
int throttleRelay = 7; /* pin 7 */
int brakeRelay = 8;    /* pin 8 */
int wiper = A0;        /* pin A0 */
int speedDial = A1;    /* pin A1 */

/* bounds for throttle mapping */
const int LOWER_THROTTLE_BOUNDS = 25;
const int UPPER_THROTTLE_BOUND = 226;

/* bounds for brake mapping */
const int LOWER_BRAKE_BOUND = 21; // adjusted to deal with intermittent braking
const int UPPER_BRAKE_BOUND = 234;

/*bounds for steering mapping */
const int LOWER_STEER_BOUND = 0;
const int UPPER_STEER_BOUND = 4096;

/* empirical potentiometer bounds */
const int LOWER_STEER_POT_BOUND = 310;
const int UPPER_STEER_POT_BOUND = 620;

/* Neutral steer value */
const float NEUTRAL_STEER = 2.5; // voltage to indicate "no turn" steering

/* control signals for steering, break, and throttle */
double steeringTarget = 50; // set steering wheel position to 50% which should be middle
int brakeTarget = 0;
int throttleTarget = 0;
int speedDialTarget = 50;  // 50% of desired speed (will be normalized up the pipeline)

const float STEER_VOLT_MAX_OFFSET = .7;
const float STEER_VOLT_MIN_OFFSET = .3;

/* upper and lower bounds of PID output */
const int LOWER_PID_BOUND = -255;
const int UPPER_PID_BOUND = 255;

/*
   Input: currentSteeringPot
   Output: pidSignal
   Setpoint: steeringTarget
   Kp: 10 (proportional term)
   Ki: 2.0 (integral term)
   Kd: 1 (derivative term)
   Controller Direction: DIRECT
*/

/*Values for the pid*/
double currentSteeringPot = -1;
double smoothedSteeringSignal = -1;
double pidSignal = -1;

const float KP = 30;  // proportional gain default: 10
const float KI = 2.0; // integral gain
const float KD = 1.19;   // derivative gain
PID myPID(&currentSteeringPot, &pidSignal, &steeringTarget, KP, KI, KD, DIRECT);

/* magic numbers */
const int MAGIC_START = 42; // start byte for incoming messages
const int MAGIC_END = 21;   // end byte for incoming messages

/* objects to handle the two DACs on I2c*/
Adafruit_MCP4725 dac1;
Adafruit_MCP4725 dac2;

/* Main program setup */
void setup()
{
  // set up serial
  Serial.begin(57600);
  while (!Serial)
  {
    delay(15);
  }

  // set up DACs
  dac1.begin(0x63); // i2c address for device
  dac2.begin(0x62); // i2c address for device

  // set up relays
  pinMode(throttleRelay, OUTPUT);
  pinMode(brakeRelay, OUTPUT);

  // set up outputs
  pinMode(throttle, OUTPUT);
  pinMode(brake, OUTPUT);

  // set up wiper
  pinMode(wiper, INPUT);

  // set up speed dial
  pinMode(speedDial, INPUT);

  // Serial.println("STARTING");

  // setup PID
  myPID.SetMode(AUTOMATIC);
  myPID.SetOutputLimits(LOWER_PID_BOUND, UPPER_PID_BOUND);
  myPID.SetSampleTime(20);
}

/* Main program loop */

long last_heart_beat = 0;
unsigned int heart_beat_counter = 0;
void loop()
{
  delay(1);
  readCommands();
  steer();
  setThrottle();
  setBrake();

  // Read in value of speed potentiometer
  // TODO: Must error check for min-max threshold and set speed to default if error (speed could hurt someone)
  speedDialTarget = analogRead(speedDial);


  // Send a byte array of data type string in the format:
  // "[MagicNumber1][MagicNumber2]SteeringTarget,ThrottleTarget,BreakTarget,SpeedDialTarget\n"
  while (abs(millis() - last_heart_beat) > 50)
  {
    Serial.print(steeringTarget);
    Serial.print(",");
    Serial.print(throttleTarget);
    Serial.print(",");
    Serial.print(brakeTarget);
    Serial.print(",");
    Serial.println(speedDialTarget);


    last_heart_beat = millis();
    heart_beat_counter++;
  }
}

void readCommands()
{

  // values read in from serial
  int firstByte = Serial.read();
  int secondByte = Serial.read();
  int throttleCommand = -1;
  int brakeCommand = -1;
  int steeringCommand = -1;

  // check to see if you have gotten the magic numbers.
  if (firstByte == MAGIC_START && secondByte == MAGIC_END)
  {

    // Read in throttle, brake, and steering data
    throttleCommand = Serial.read();
    brakeCommand = Serial.read();
    steeringCommand = Serial.read();

    if (throttleCommand != -1 && brakeCommand != -1 && steeringCommand != -1)
    {
      throttleTarget = throttleCommand;
      brakeTarget = brakeCommand;
      steeringTarget = steeringCommand;
      // Serial.print("Steering Target= ");
      // Serial.println(steeringTarget);
    }
  }
}

void setThrottle()
{
  int val = map(throttleTarget, 0, 255, LOWER_THROTTLE_BOUNDS, UPPER_THROTTLE_BOUND);
  analogWrite(throttle, val);

  if (throttleTarget == 0)
  {
    digitalWrite(throttleRelay, LOW);
  }
  else
  {
    digitalWrite(throttleRelay, HIGH);
  }
}

void setBrake()
{
  int val = map(brakeTarget, 0, 255, LOWER_BRAKE_BOUND, UPPER_BRAKE_BOUND);
  analogWrite(brake, val);

  if (brakeTarget == 255)
  {
    digitalWrite(brakeRelay, LOW);
  }
  else
  {
    digitalWrite(brakeRelay, HIGH);
  }
}

// process steering command
void steer()
{
  if (steeringTarget != -1)
  {
    // read in the potentiometer value and map from 0 (full left) to 100 (full right)
    if (smoothedSteeringSignal == -1)
      smoothedSteeringSignal = analogRead(wiper);
    else
    {
      smoothedSteeringSignal = smoothedSteeringSignal * .9 + analogRead(wiper) * .1;
    }
    // Serial.print("Pot Absolute Value: ");
    // Serial.println(currentSteeringPot);
    currentSteeringPot = mapf(smoothedSteeringSignal, LOWER_STEER_POT_BOUND, UPPER_STEER_POT_BOUND, 0.0, 100.0);
    // Serial.print("CURR POT ");
    // Serial.println(currentSteeringPot);
    myPID.Compute();
    // Serial.print("RAW COMPUTE ");
    // Serial.println(pidSignal);
    float signal = mapf(pidSignal, LOWER_PID_BOUND, UPPER_PID_BOUND, -STEER_VOLT_MAX_OFFSET, STEER_VOLT_MAX_OFFSET);
    // Serial.print("MAPPED SIGNAL: ");
    // Serial.println(signal);
    setSteerVoltages(signal);
  }
}

/* sends a steeringTarget voltage to both left and right steering channels */
void setSteerVoltages(float signal)
{
  // check if values are valid - must be between 2.0 & 3.0 inclusive and sum up to 5.0
  int finalLeft = mapf(NEUTRAL_STEER - signal, 0.0, 5.0, LOWER_STEER_BOUND, UPPER_STEER_BOUND);
  int finalRight = mapf(NEUTRAL_STEER + signal, 0.0, 5.0, LOWER_STEER_BOUND, UPPER_STEER_BOUND);

  // Serial.print("IF LEFT VOLT: ");
  // Serial.println(finalLeft);
  // Serial.print("IF RIGHT VOLT: ");
  // Serial.println(finalRight);

  dac1.setVoltage(finalLeft, false);
  dac2.setVoltage(finalRight, false);
}

/* map function for a float value */
float mapf(float x, float inMin, float inMax, float outMin, float outMax)
{
  return (x - inMin) * (outMax - outMin) / (inMax - inMin) + outMin;
}

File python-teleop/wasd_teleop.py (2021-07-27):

"""
    wasd_teleop.py - Used to send keyboard-commands to cart_teleop.ino for manual control of the cart

        Author: Brandon parr
        Version: 1.0
"""

import curses
import sys
import math
import serial #this package is pySerial not serial!!!
import time
import bitstruct
import numpy as np

from serial.tools.list_ports import comports
from sys import platform

cart_port = '/dev/ttyUSB9'  #hardcoded depending on computer

#cart_port = '/dev/cu.usbserial-1463340' #Mac OS value

# assume the first port we find that has 'usbserial' in the name is the one from the mac
def detect_com_port():
    ports_list = comports()

    for port_candidate in ports_list:
        port_name = port_candidate.device

        if 'usbserial' in port_name:
            return port_name


    return -1

""" main program funcitonality """
class teleop(object):

    # define max speed and min / max steering angle for cart
    MAX_SPEED = 255
    MIN_ANGLE = 0
    MAX_ANGLE = 100

    def __init__(self):

        # initialize current velocity and steering angle variables
        self.cur_vel = 0  # (0 - 255)
        self.cur_angle = 50  # 50 is middle, (0 - 100)

        self.prev_key = 1

        # try to set up serial port for sending commands to arduino
        try:
            self.cart_ser = serial.Serial(cart_port, 57600, write_timeout=0)
        except Exception as e:
            print("ERROR. . .could not connect to arduino: " + str(e))
            exit(0)

        # start curses wrapper to get input
        curses.wrapper(self.get_input)

    """ main wrapper for curses """
    def get_input(self, stdscr):
        curses.use_default_colors()
        for i in range(0, curses.COLORS):
            curses.init_pair(i, i, -1)

        stdscr.nodelay(True)
        stdscr.addstr(0, 0, 'Move with WASD, Z for brake, X for hard stop and Y for centering the wheel.')
        stdscr.addstr(1, 0, 'CTRL-C to exit')
        stdscr.addstr(7, 0, 'Throttle val:')
        stdscr.addstr(8, 0, 'Brake val:')
        stdscr.addstr(9, 0, 'Steering val:')

        # runs indefinitely, getting user input
        while True:

            keyval = stdscr.getch()
            if keyval == ord('w'):
                self.cur_vel = min(self.MAX_SPEED, self.cur_vel + 15)
            elif keyval == ord('a'):
                self.cur_angle = max(self.MIN_ANGLE, self.cur_angle - 10)
            elif keyval == ord('s'):
                self.cur_vel = max(0, self.cur_vel - 15)
            elif keyval == ord('d'):
                self.cur_angle = min(self.MAX_ANGLE, self.cur_angle + 10)
            elif keyval == ord('y'):
                self.cur_angle = 50
            elif keyval == ord('x'):
                self.cur_vel = 0
            elif keyval == ord('z'):
                self.brake(self.cur_vel / 255.0 * 3, stdscr)
                self.cur_vel = 0

            self.send_cmd(self.cur_vel, 0, self.cur_angle, stdscr)
            self.prev_key = keyval
            time.sleep(1 / 10.)

    """ constructs brake command """
    def brake(self, delay, stdscr):
        rate = 10.
        steps = int(delay * rate)
        for brake in np.linspace(0, 255, steps, endpoint=True):
            self.send_cmd(0, int(brake), self.cur_angle, stdscr)
            time.sleep(1. / rate)
            stdscr.getch()

    """ sends a set of throttle, brake, and steering commands to the arduino """
    def send_cmd(self, throttle, brake, steering, stdscr):
        data = bytearray(b'\x00' * 5)
        bitstruct.pack_into('u8u8u8u8u8', data, 0, 42, 21,
                            throttle, brake, steering)
        self.cart_ser.write(data)

        stdscr.addstr(7, 0, 'Throttle val: ' + str(throttle) + '  ')
        stdscr.addstr(8, 0, 'Brake val:    ' + str(brake) + '  ')
        stdscr.addstr(9, 0, 'Steering val: ' + str(steering) + '  ')

if __name__ == "__main__":

    if platform == "linux" or platform == "linux2":
        cart_port = '/dev/ttyUSB9'
    elif platform == "darwin":
        cart_port=detect_com_port()
    #elif platform == "win32":

    print("Using serial port: "+str(cart_port))

    teleop()

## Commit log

2020-06-03 commit of current arduino code
2020-08-19 remove some prints
2020-11-05 Upload schematic of current controller board schematics
2020-11-12 Add libs folder to hold Arduino teleop libraries
2020-11-12 Deprecate old PWM teleop board
2020-11-17 Copy in Arduino libraries from local install
2020-11-24 Add requirements file to ensure correct packages are installed
    [wasd_teleop.py]
2021-01-21 Add heartbeat and silence all prints
2021-01-21 Create PCBFiles
2021-01-21 Added Dick's PCB Files
    PCB Designs
    [JACart.brd, JACart.kicad_pcb, JACart.sch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]
2021-02-09 Add golf cart wiring diagrams
2021-03-08 Adding additional Eagle design files
    [Motherboard_1.brd, Motherboard_1.sch, Motherboard_2.brd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]
2021-03-08 Re-organize and delete hidden files
    [JACart.brd, JACart.kicad_pcb, JACart.sch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]
2021-04-29 Resolve braking error and reduce verbosity
    [cart_teleop_dac.ino]
2021-05-06 Add abs() to ensure we avoid overflow errors
    [cart_teleop_dac.ino]
2021-06-01 Enable teleop to scan for correct port on MacOS
    [wasd_teleop.py]
2021-06-16 Update chart schematics
2022-05-12 updated PIDs for steering for Comm Circuit Board v1.0
2022-05-12 Added in CommBoardPCBFiles (new all-in-one board)
